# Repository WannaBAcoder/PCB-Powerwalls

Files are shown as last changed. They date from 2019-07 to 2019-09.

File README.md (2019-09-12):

# PCB-Powerwalls
This is the public file Repository for the [DIY PCB Powerwalls Community](https://www.facebook.com/groups/2573968699280898/). The projects are developed and maintained by **Vinnie Maro** and **Shaun Bond**.

We are developing a PCB alternative to common powerwall building techniques for 18650(and similar) batteries. This system has been developed with maintainability, expandability, and practicality in mind. 

For additional DIY Powerwall building resources, please check out some of the many other active facebook groups and forums:
* [DIY Powerwalls](https://www.facebook.com/groups/323586824654552/)
* [Jehu's DIY Powerwalls](https://www.facebook.com/groups/183620862292017/)
* [DIY Powerwall - easy](https://www.facebook.com/groups/244099703167519/)
* [Second Life Storage](https://secondlifestorage.com/index.php)

## Features in Development
To see features currently in development or exploration, check out our [issues](https://github.com/WannaBAcoder/PCB-Powerwalls/issues) page.

## 15s4p PCB

The 15s4p battery board is a stackable solution that reduces the amount of wiring required by placing all series and balance connections through standoffs that structurally connect the boards. Batteries mount to both sides of the PCB, in a variety of ways. Each cell is individually fused for added safety.

### 1. Plastic battery holders

You can choose to use plastic cell holders that are available in many through-hole and surface mount packages. For the through-hole packages, you must bend the pins at a 90 degree angle so that the holders sit as flat as possible.

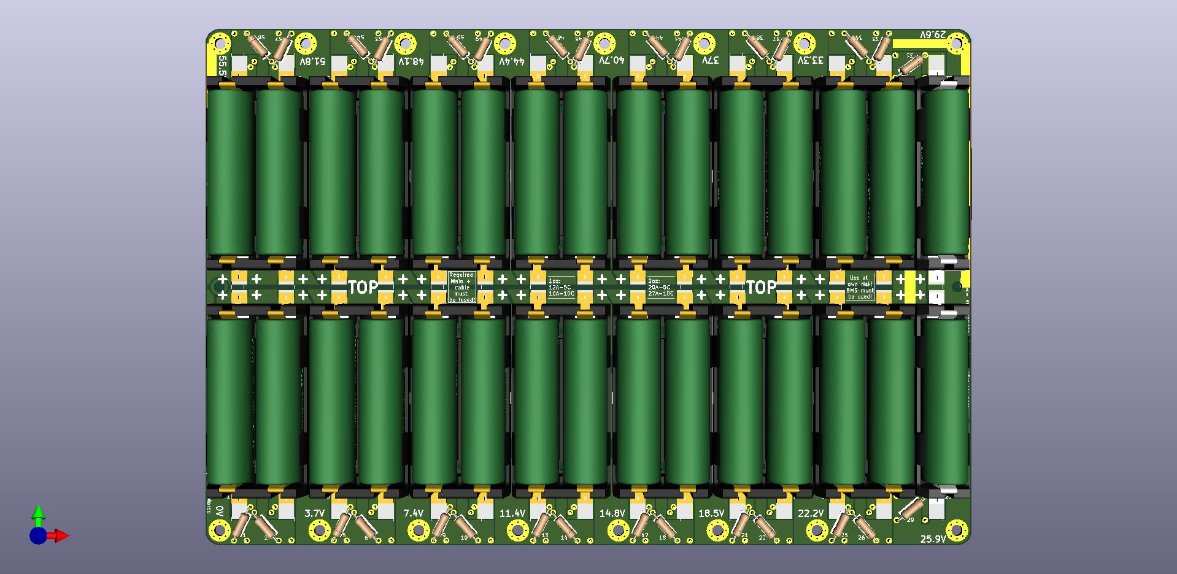
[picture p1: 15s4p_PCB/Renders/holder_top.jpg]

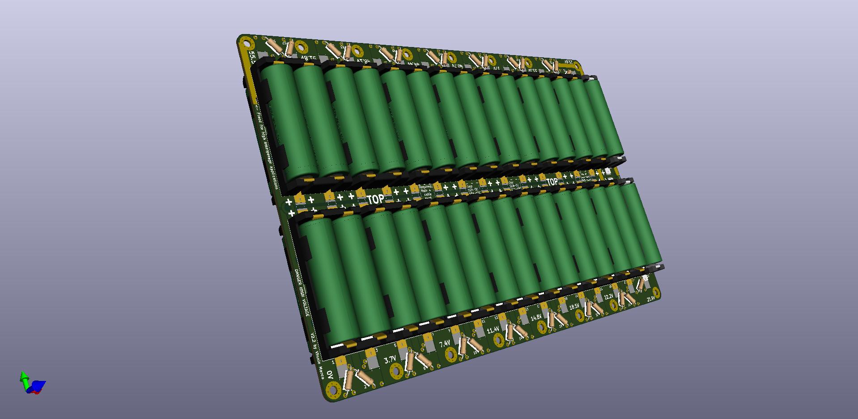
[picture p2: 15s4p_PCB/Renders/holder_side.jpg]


### 2. Spring clips

A cheaper alternative to plastic holders is spring clips. The clips work like traditional battery holders with springs, but these require the use of zip ties to hold the cells in place.

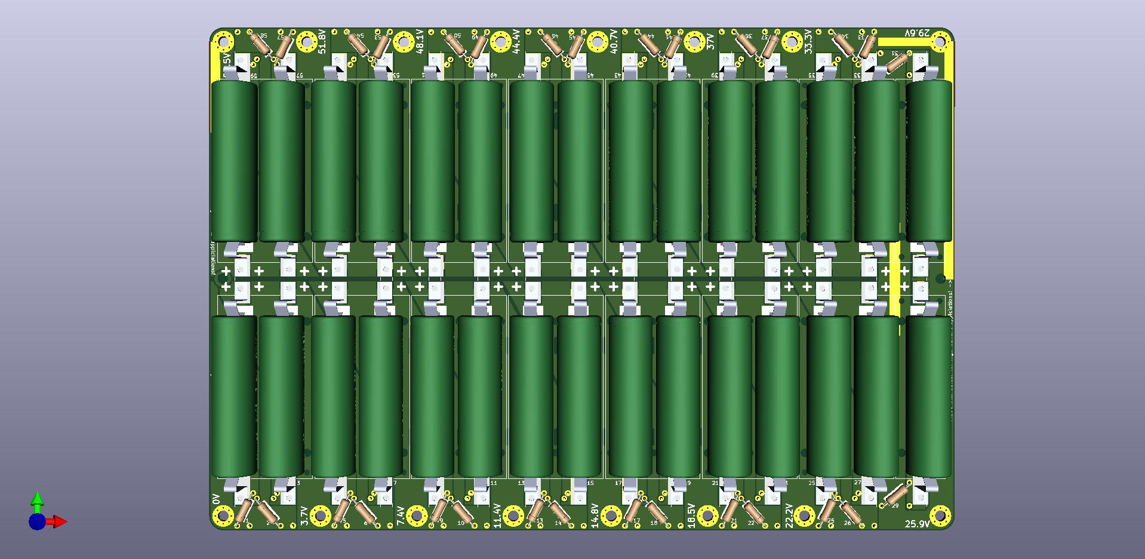
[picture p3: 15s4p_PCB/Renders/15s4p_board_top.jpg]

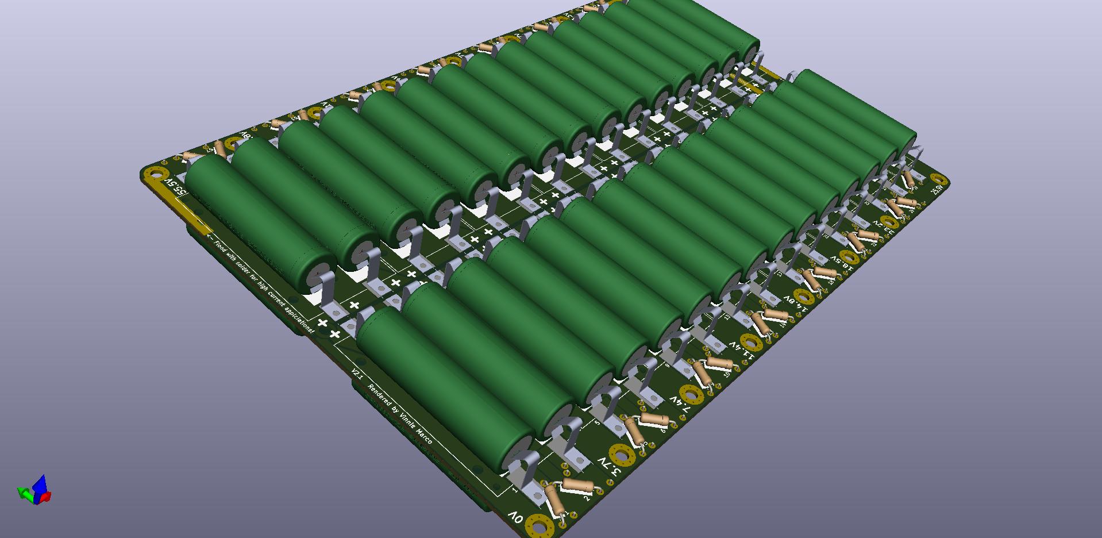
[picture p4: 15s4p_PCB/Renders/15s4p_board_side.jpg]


### 3. Fuse wire

The last option is to use fuse wire. You will still need to use zip ties to hold the cells in place, but you can solder the fuse wire directly to the PCB pads, and remove the need for populating fuses(you will need to short the fuse pads to do this). You can also use large fuse wire and still use fuses, if desired. Spotwelding fuse wire to the batteries and soldering the other end to the PCB pads is recommended.

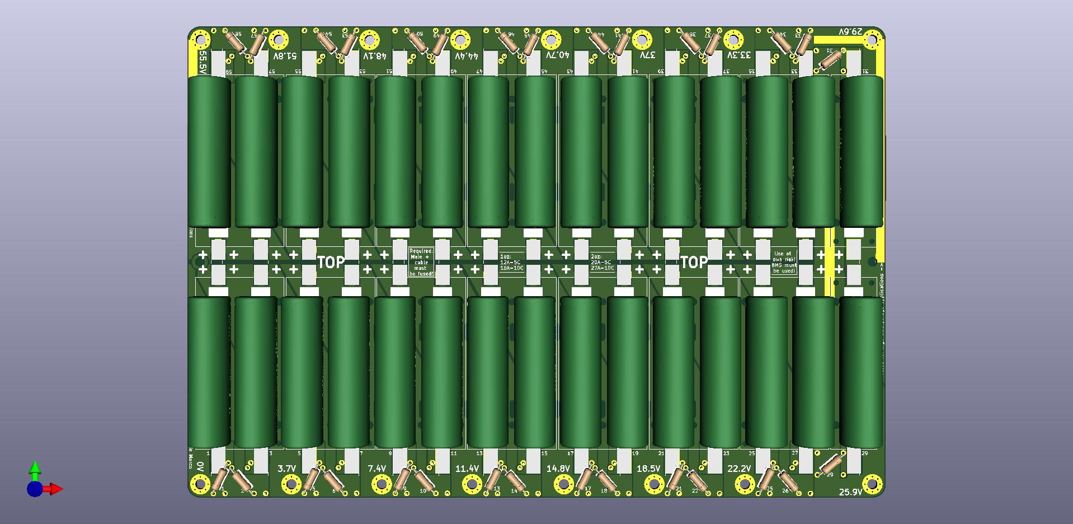
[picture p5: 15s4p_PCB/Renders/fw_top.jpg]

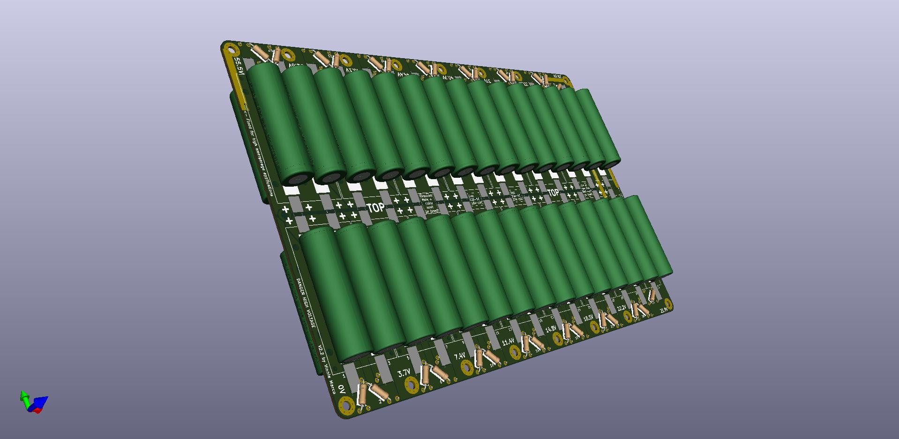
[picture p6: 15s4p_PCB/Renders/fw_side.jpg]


### 7s Adapter PCB

The 7s Adapter PCB was created to take our popular 15s4p design and convert it into a 7s8p PCB. We do this by leaving the out the 8s cells, which creates two 7s groups that get connected in parallel. It is recommended to use at least one of these adapter PCBs for every 5 boards, or 20A of main fuse(which is 10A load on each of these boards). This board also joins the battery stacks with standoffs. It's important to equally space these boards within a pack for best current distribution. For example, a 12 battery board stack could use 3 adapter boards, spaced every 4 boards.

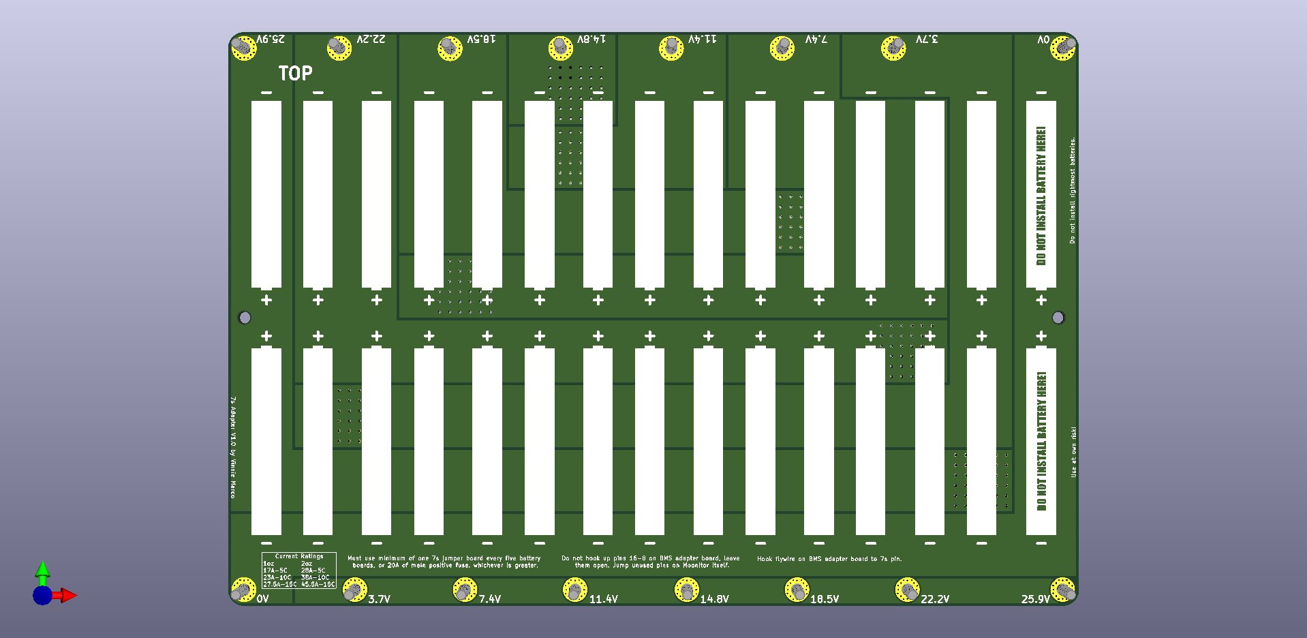
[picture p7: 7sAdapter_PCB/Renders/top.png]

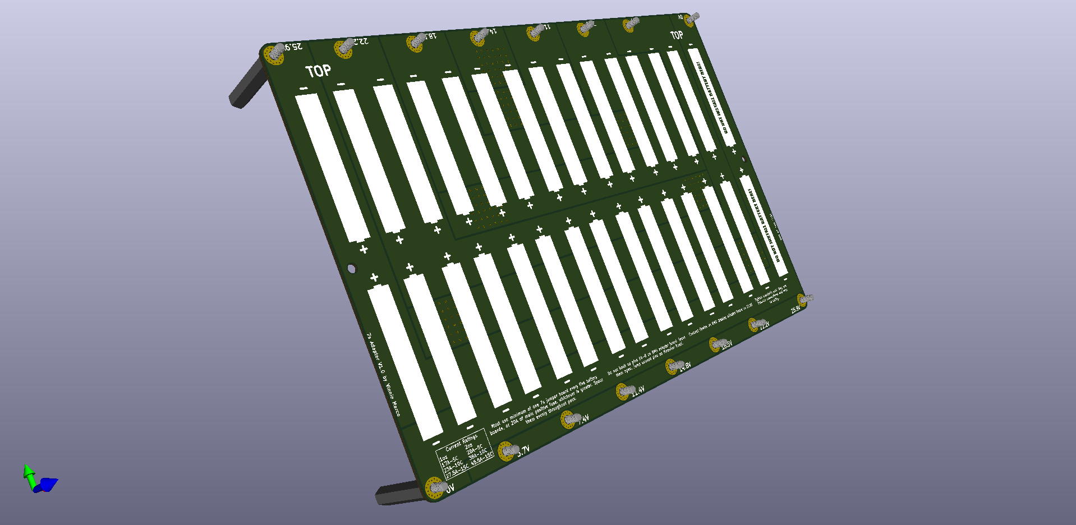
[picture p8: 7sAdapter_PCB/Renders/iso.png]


### BMS/Display Adapter PCB

The BMS/display adapter board helps the user connect a [Moonitor](https://www.sarperonal.com/product/6s-16s-solar-plc-li-ion-battery-protection-system/), or a variety of BMS systems to the battery PCB stacks, and is capable of supporting ~5A balance current. This board also includes spaces to add series-level voltage displays, but they can be disabled if not desired.  You can also use this board with the 7s adapter board configurations.

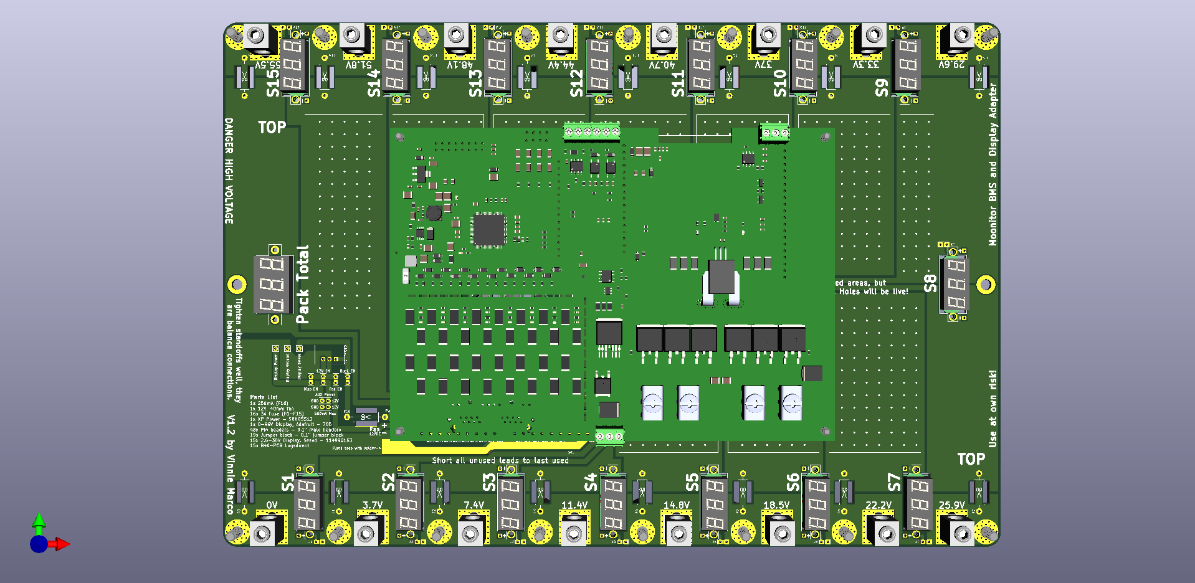
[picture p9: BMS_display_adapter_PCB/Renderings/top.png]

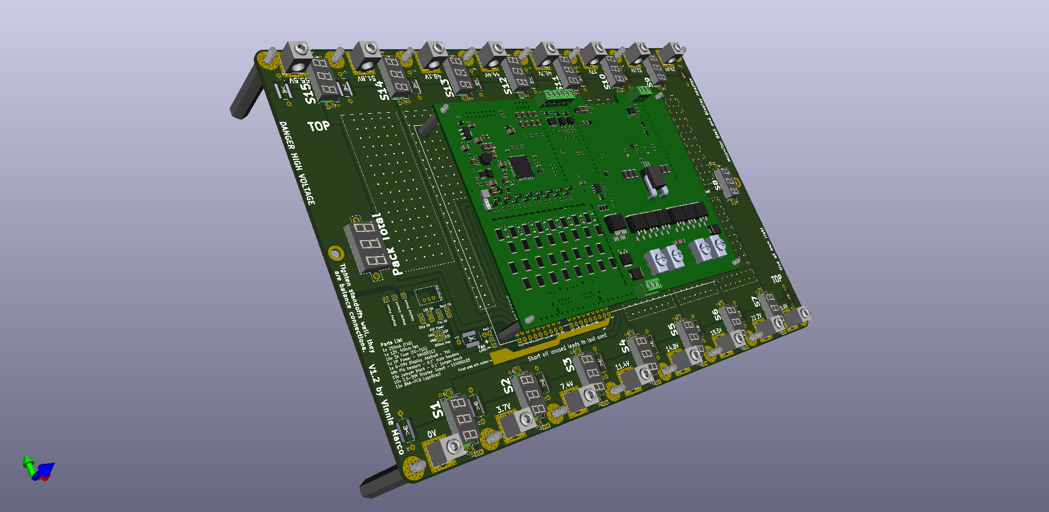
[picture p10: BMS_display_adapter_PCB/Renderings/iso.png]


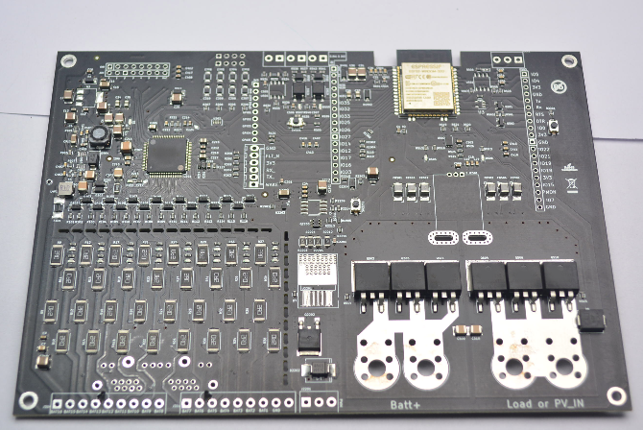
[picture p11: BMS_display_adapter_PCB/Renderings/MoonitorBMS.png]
moonitor view


## Building Your Own

### Ordering the PCBs

You can order your own boards from any number of PCB manufacturers. Many of our supporters use [JLCPCB.com](https://jlcpcb.com/quote).

**Recommended manufacturing options:**
* PCB thickness - 1.6mm
* PCB color-Your choice (black is not available for 2oz copper orders)
* Surface finish - HASL(with lead)
* Copper weight - 1oz or 2oz **(Higher current applications use 2oz)**
* All other options can be left as default

### Ordering Parts
#### Common Parts
* M4 Standoffs(40mm for SMD plastic holders, 45mm for through-hole plastic holders, may be able to make 40mm work with zip tie methods if zipties are alternated. Not confirmed at this time)
    -  [Nickel plated steel](https://www.aliexpress.com/item/33009686876.html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)
    - [Brass](https://www.aliexpress.com/item/32909068891.html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)
    
* 60x Glass Axial Fuses
**Choosing the right fuse is based on tradeoff between usebility and saftey. Even a 0.5A fuse can't protect against all 18650(and similar) failure modes. Shaun Bond's testing suggests 0.5A fuses are the ideal size for safety, but impractical for all massive builds with low load. You should still consider your pack-loading characteristics when choosing them.**
  - [0.5A](https://www.ebay.com/itm/200Pcs-Glass-Fuse-Tube-Axial-With-Lead-Wire-Fast-Blows-Fuse-3x10mm-250V-0-5A-US-/283481427034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)
  - [1A](https://www.ebay.com/i/372678478703?itemid=372678478703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)
  - [1.5A](https://www.ebay.com/itm/200Pcs-Glass-Fuse-Tube-Axial-With-Lead-Wire-Fast-Blows-Fuse-3x10mm-250V-1-5A-P/401758396012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)
  - [2A](https://www.ebay.com/i/283303754606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)
  - [3A](https://www.ebay.com/itm/200Pcs-Glass-Fuse-Tube-Axial-With-Lead-Wire-Fast-Blows-Fuse-3x10mm-250V-3A-US/283485834501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)
  - [aliexpress](https://www.aliexpress.com/item/32910625856.html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)
    
#### 15s4p PCB
**Be sure to choose the right holders for your desired build. For plastic holder builds, the quantities assume using only 1-cell and 2cell, or 3-cell and 4-cell holders per board. 
* Plastic Holders
  - 4x 1-cell holder([Keystone 1042](https://www.keyelco.com/product.cfm/product_id/918))
    - [mouser](https://www.mouser.com/ProductDetail/Keystone-Electronics/1042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)
    - [aliexpress](https://www.aliexpress.com/item/32843455571.html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,searchweb201602_4,searchweb201603_52)

  - 28x 2-cell holder([Keystone 1048](https://www.keyelco.com/product.cfm/product_id/920)) 
    - [mouser](https://www.mouser.com/ProductDetail/Keystone-Electronics/1048?qs=%2F7TOpeL5Mz5jXkg8vI8Dyw%3D%3D)
    - [aliexpress](https://www.aliexpress.com/item/32810550974.html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,searchweb201602_4,searchweb201603_52)

  - 4x 3-cell holder(BK-18650-PC6)(through-hole)
    - [digikey](https://www.digikey.com/product-detail/en/mpd-memory-protection-devices/BK-18650-PC6/BK-18650-PC6-ND/2330514)
    - [aliexpress](https://www.aliexpress.com/item/32855470302.html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,searchweb201602_7,searchweb201603_53)

  - 24x 4-cell holder(BK-18650-PC8)(through-hole)
    - [digikey](https://www.digikey.com/product-detail/en/mpd-memory-protection-devices/BK-18650-PC8/BK-18650-PC8-ND/2330515)
    - [aliexpress](https://www.aliexpress.com/item/32813957846.html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,searchweb201602_7,searchweb201603_53)
       
* 120x Spring clips([Keystone 5331](https://www.keyelco.com/product.cfm/product_id/823))
    - [mouser](https://www.mouser.com/ProductDetail/Keystone-Electronics/5331?qs=poiiR8sYdC9oC9Ij8wI9kA%3D%3D)
    - [newark](https://www.newark.com/keystone/5331/battery-contact-a-aa-2-3a-cell/dp/25T0473)
 
#### BMS/Display Adapter PCB
* 1x Total voltage pack voltage display(Adafruit 705)
    - [mouser](https://www.digikey.com/products/en/industrial-automation-and-controls/panel-meters/805?k=adafruit%20705)
    - [Adafruit](https://www.adafruit.com/product/705
    
* 15x Series-group voltage display(Seeed 114990163)
    - [mouser](https://www.mouser.com/ProductDetail/Seeed-Studio/114990163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)
    - [Seeed](https://www.seeedstudio.com/0-28-Inch-LED-digital-DC-voltmeter-Green-p-2287.html)
    - [Digikey](https://www.digikey.com/products/en/industrial-automation-and-controls/panel-meters/805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) has other colors too.
    
* 1x 12VDC 40x40mm PC Fan(2-wire)
    - Tons of these on [Amazon](https://www.amazon.com/WINSINN-Brushless-40x40x10mm-Extruder-Makerbot/dp/B0757LXKST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)

* 1x 75VDC to 12V buck converter module.
    - [mouser](https://www.mouser.com/ProductDetail/XP-Power/SRH05S12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)
    - [Digikey](https://www.digikey.com/products/en?keywords=srh05s12)
    
* 1x 0.25A glass fuse
    - [Digikey](https://www.digikey.com/product-detail/en/littelfuse-inc/0251.250NRT1L/F5997CT-ND/4146349)
    - [mouser](https://www.mouser.com/ProductDetail/Littelfuse/0251250NRT1L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)
    - [Ebay](https://www.ebay.com/itm/200Pc-Glass-Tube-Fuse-Metal-Axial-Double-Hat-Fast-Blow-Fuse-3-6x10mm-250V-0-25A/264389811818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)

* 16x B4A Lugs
    - [hex](https://lugsdirect.com/B4A-PCB-HEX.html)
    
* 0.1" male pin headers
    - [aliexpress](https://www.aliexpress.com/item/32899255706.html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,searchweb201602_7,searchweb201603_53)
    
* 0.1" jumper blocks
    - [aliexpress](https://www.aliexpress.com/item/32972892184.html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,searchweb201602_7,searchweb201603_53)
 
* Moonitor BMS

You can purchase this BMS from the Moonitor team on their [website](https://www.sarperonal.com/product/6s-16s-solar-plc-li-ion-battery-protection-system/). You can also contact [them](https://www.sarperonal.com/contact-us/) directly for more information.

### Building Instructions and Documentation
Check out the [wiki](https://github.com/WannaBAcoder/PCB-Powerwalls/wiki) for assembly instructions, and additional information.

## Versioning

Each powerwall PCB has its own revision in the form of VX.X. In addition to this, we version the entire system package in a release in the form of RX.0. See the latest release for the most recent hardware package. Whenever any of the hardware in a package changes, the PCB version and package release will be updated. PCB versions are printed on all PCBs for easy identification.

## Contributing

Although the kicad source files are available, the safety considerations that go into this project make it potentially unsafe to modify; do so at your own risk! You can always contribute to the development of this project by suggesting improvements or new features desired by reporting them as [issues](https://github.com/WannaBAcoder/PCB-Powerwalls/issues).

## License

This project is licensed under the CERN Open Hardware License - see the [LICENSE.txt](LICENSE.txt) file for details.

## Acknowledgments

A special thank you to the people and communities that inspired or helped develop the early versions of this hardware and helped others realize the growing potential for these designs:
* Shaun Bond
* Izz Eselam
* Paulo E Cabigao
* Dale Bliss
* Jehu Garcia 
* Andrew Hunt
* Daniel Wiermans

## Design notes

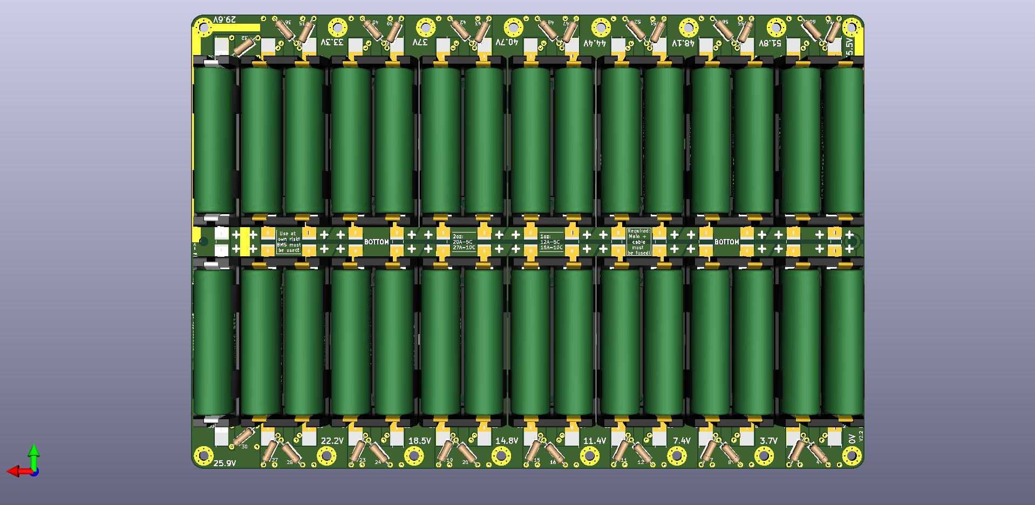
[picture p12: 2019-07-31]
15s4p_PCB/Renders/holder_bottom.jpg

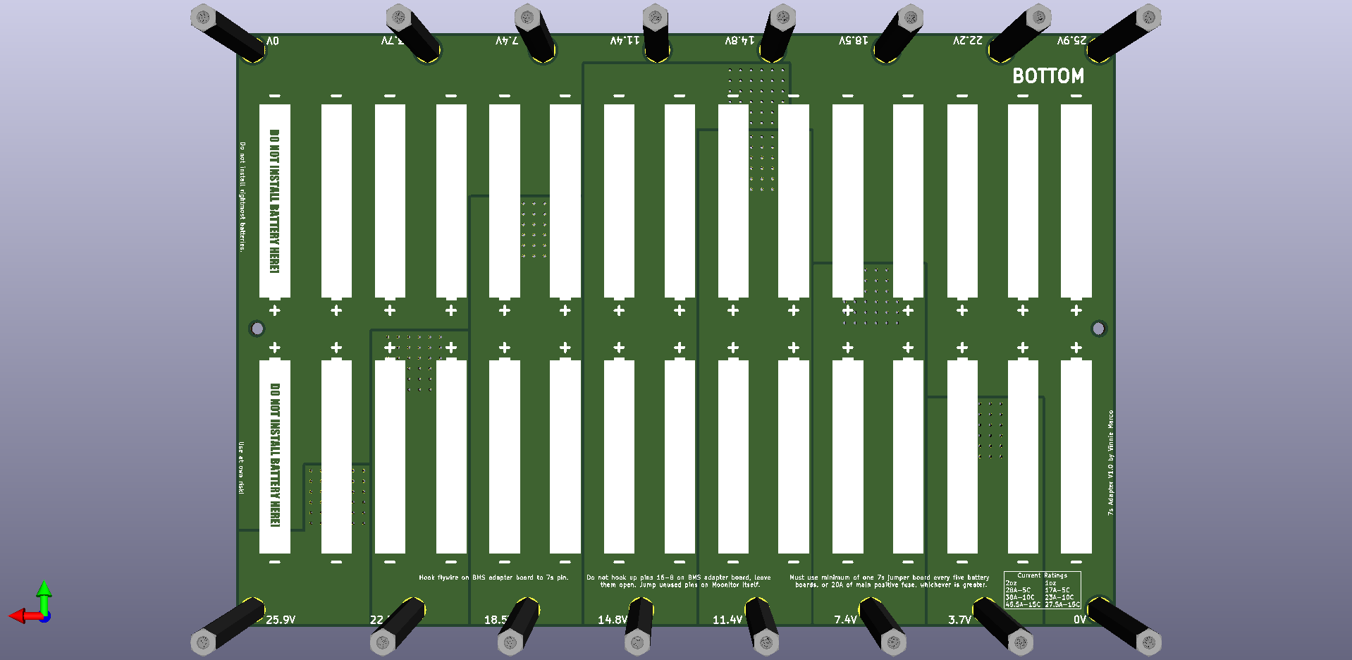
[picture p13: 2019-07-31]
7sAdapter_PCB/Renders/bottom.png

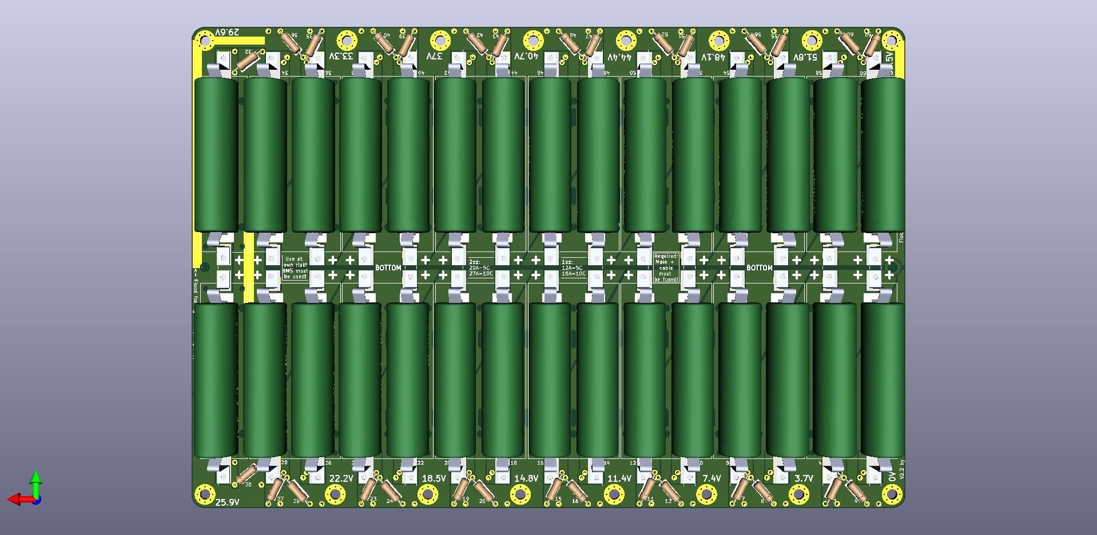
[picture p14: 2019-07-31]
15s4p_PCB/Renders/bottom.jpg

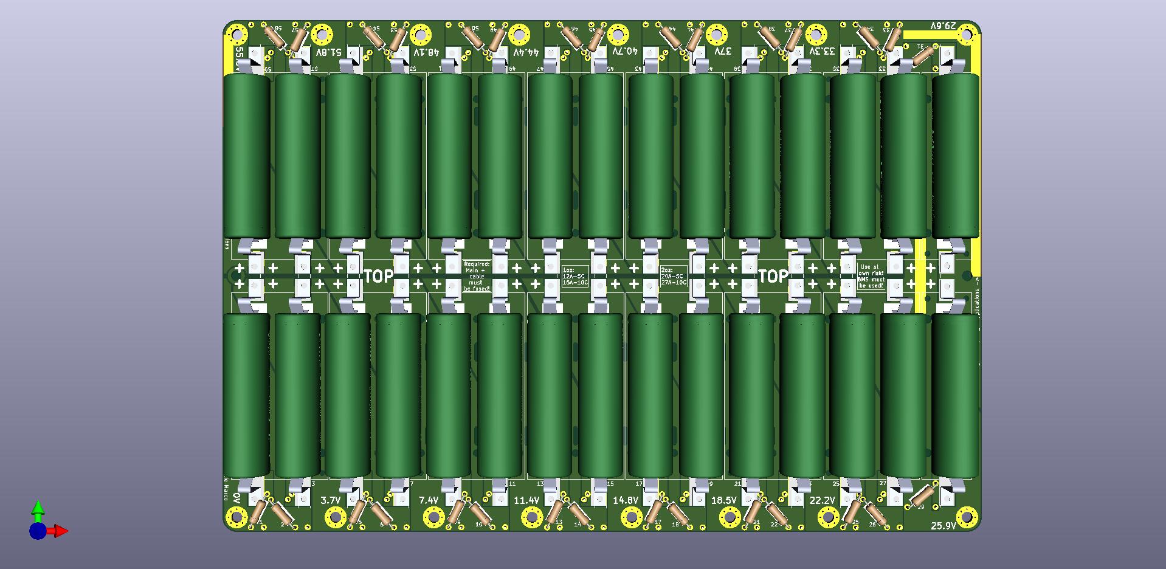
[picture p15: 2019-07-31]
15s4p_PCB/Renders/top.jpg

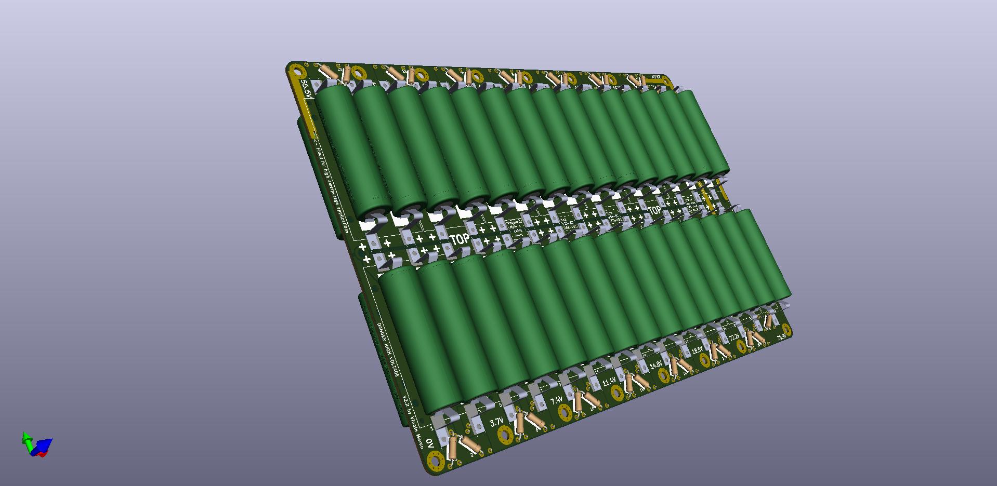
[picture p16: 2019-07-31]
15s4p_PCB/Renders/side.jpg

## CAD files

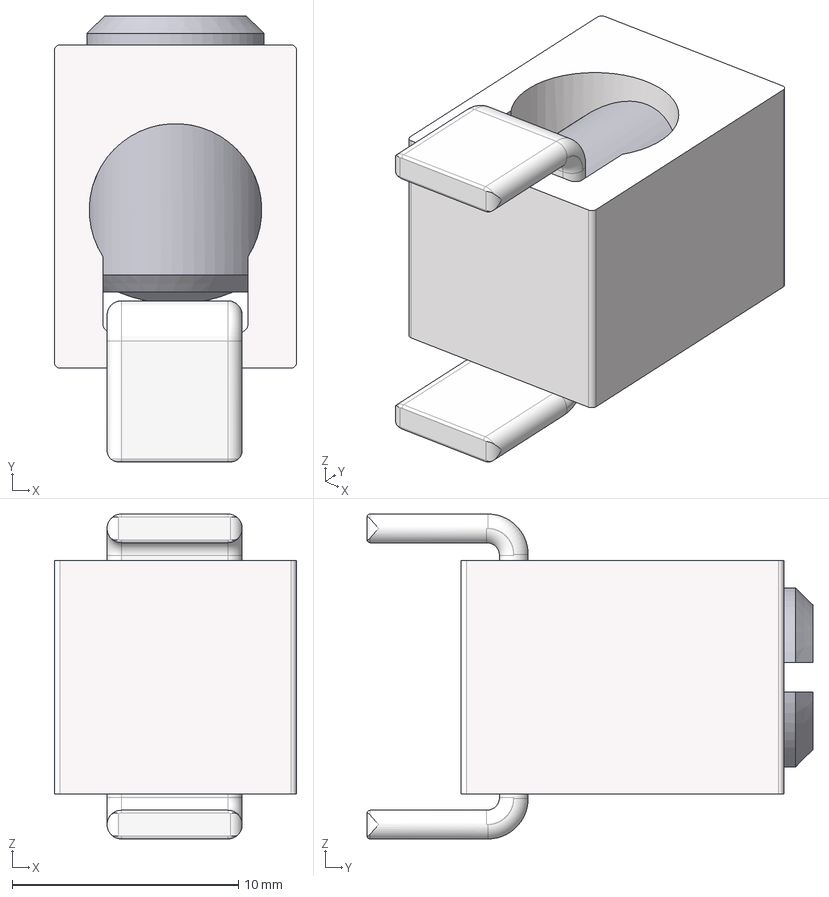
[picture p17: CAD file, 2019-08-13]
BMS_display_adapter_PCB/3D Models/_STP FILES_B2A-PCB-Assembly.stp
10.7 x 19.7 x 14.4 mm
B2A

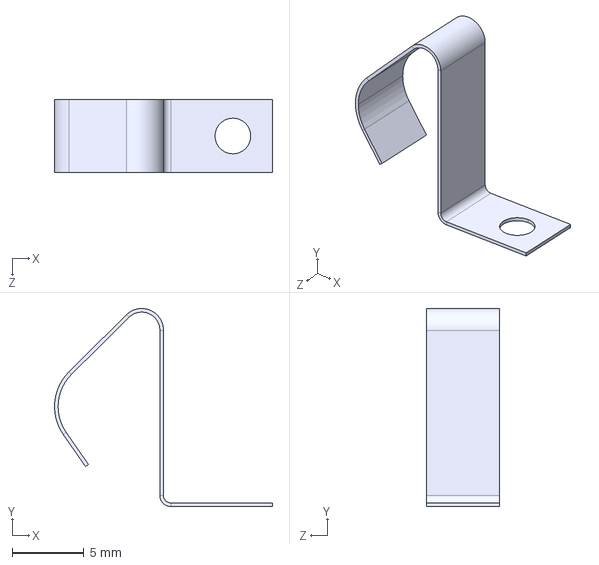
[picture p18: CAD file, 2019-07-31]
15s4p_PCB/3D Models/keystone-PN5331.STEP
15.2 x 13.8 x 5.08 mm

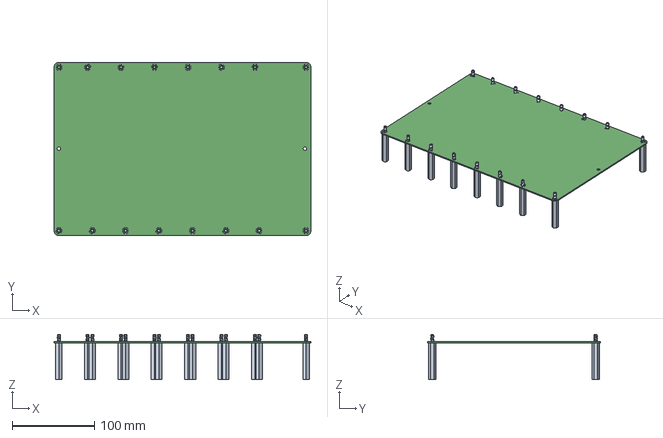
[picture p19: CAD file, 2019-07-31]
7sAdapter_PCB/7sAdapter.step
313.0 x 211.0 x 55.0 mm

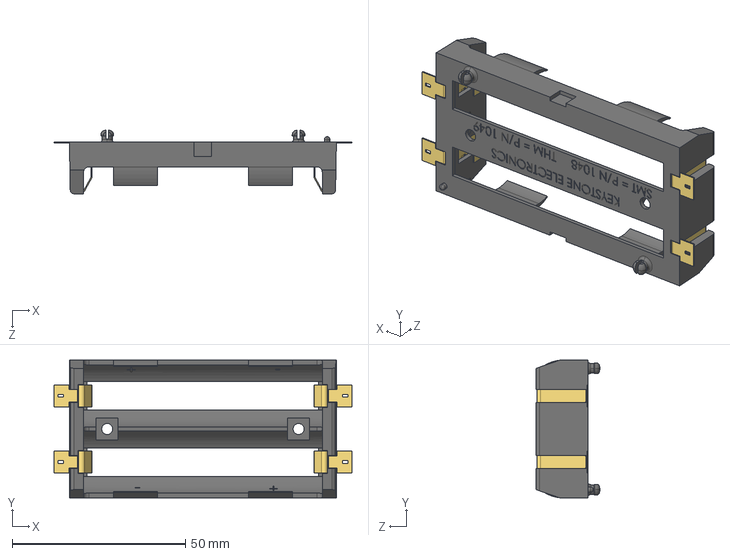
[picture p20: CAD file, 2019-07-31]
15s4p_PCB/3D Models/keystone-PN1047.STEP
86.0 x 39.8 x 18.3 mm

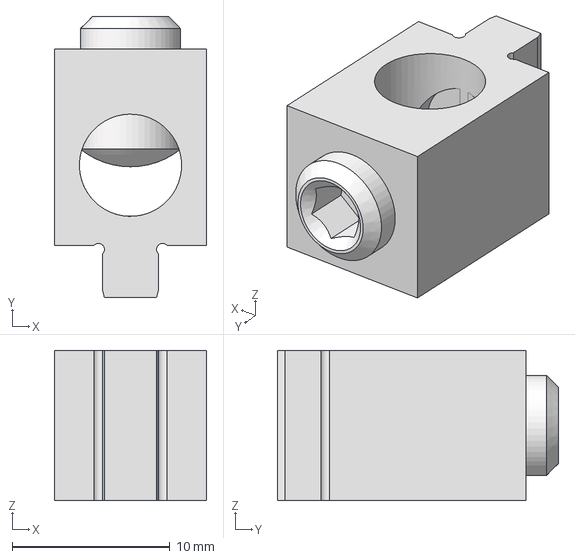
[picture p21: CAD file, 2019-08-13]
BMS_display_adapter_PCB/3D Models/_STP FILES_B4A-PCB-HEX.stp
9.65 x 17.8 x 9.53 mm
B4A-PCB

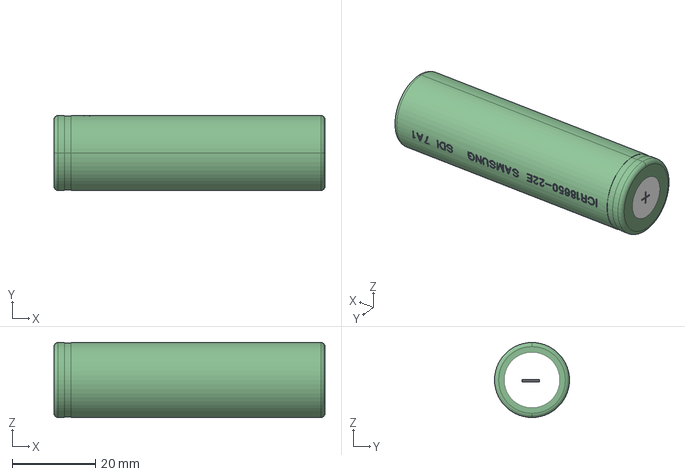
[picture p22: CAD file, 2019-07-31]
15s4p_PCB/3D Models/Battery Samsung ICR 18650 -22E.stp
65.0 x 18.0 x 18.0 mm

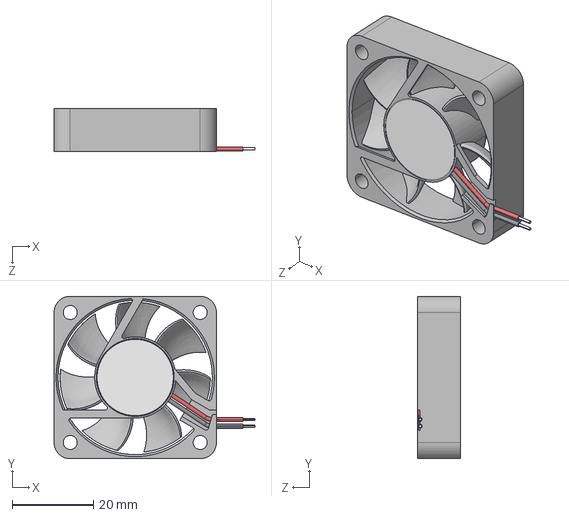
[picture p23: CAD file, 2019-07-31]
BMS_display_adapter_PCB/3D Models/40x40x10 DC Fan.STEP
49.5 x 40.0 x 10.5 mm

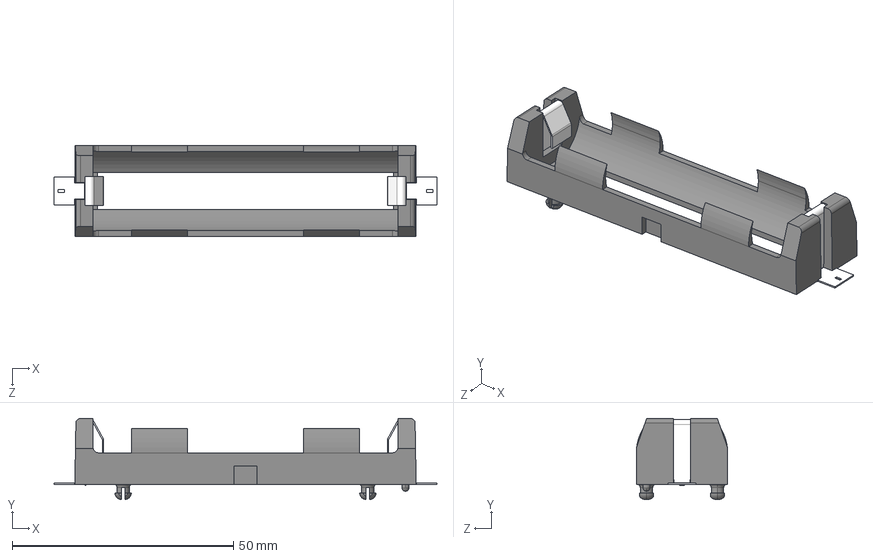
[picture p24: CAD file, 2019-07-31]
15s4p_PCB/3D Models/1042--3DModel-STEP-56544.STEP
86.5 x 18.3 x 20.7 mm

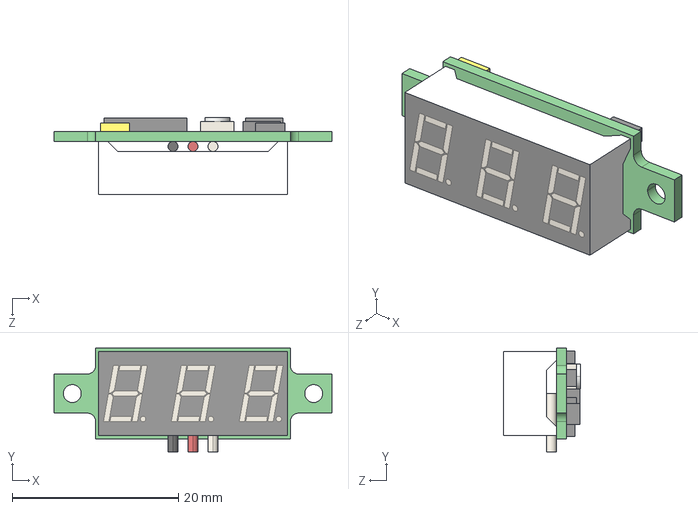
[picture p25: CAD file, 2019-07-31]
BMS_display_adapter_PCB/3D Models/LED DC 0-100V Digital Voltmeter Panel Meter.STEP
33.4 x 12.5 x 9.30 mm

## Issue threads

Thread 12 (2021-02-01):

JLCPCB.COM - Reply when sending order for BMS

xxxxminingxxxx, 2021-02-01:
Hi Sir,

Well got your order with many thanks~
Sorry to bother you, but there is an issue that we want to confirm with you before proceeding.

As shown below, the plated slots in your file are too long , there is a risk of blasting holes after tinned. can you accept that potencial risk without any quality complaint about this issue ?If yes ,we can continue this order ,as as you can check the capability listed on our website ,the maximum plated holes/slots we can accept is 6.3mm .we suggest you can change HASL to ENIG to reduce the risk .

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

Your early reply will be highly appreciated!

WannaBAcoder, 2021-02-01:
Hello,

I think they have been able to produce this before. See attached:
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

Based on that, I think it's safe to accept the risk.

Thanks,
Vinnie Marco

xxxxminingxxxx, 2021-02-06:
Hello,

I let you know that I have ordered the 15S4P boards and the BMS board.
Thanks for sharing, fantastic job!
I normally have them next week, let you know how it goes.
I will also link the Moonitor16S to this.

Mvg, Mark

Op ma 1 feb. 2021 om 16:50 schreef WannaBAcoder <notifications@github.com>:

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

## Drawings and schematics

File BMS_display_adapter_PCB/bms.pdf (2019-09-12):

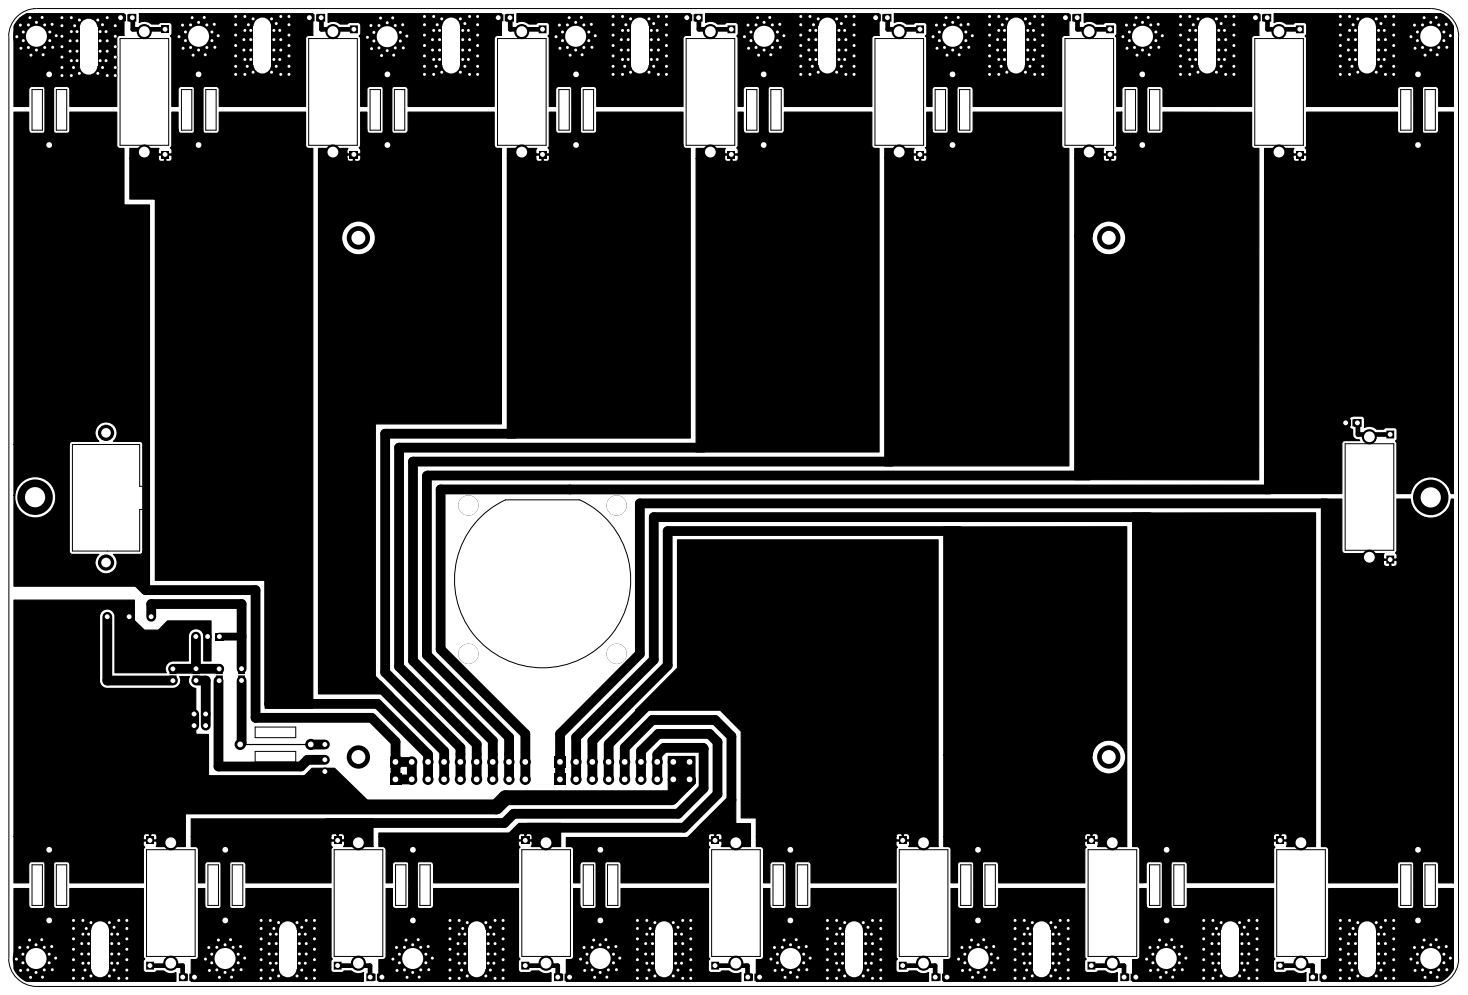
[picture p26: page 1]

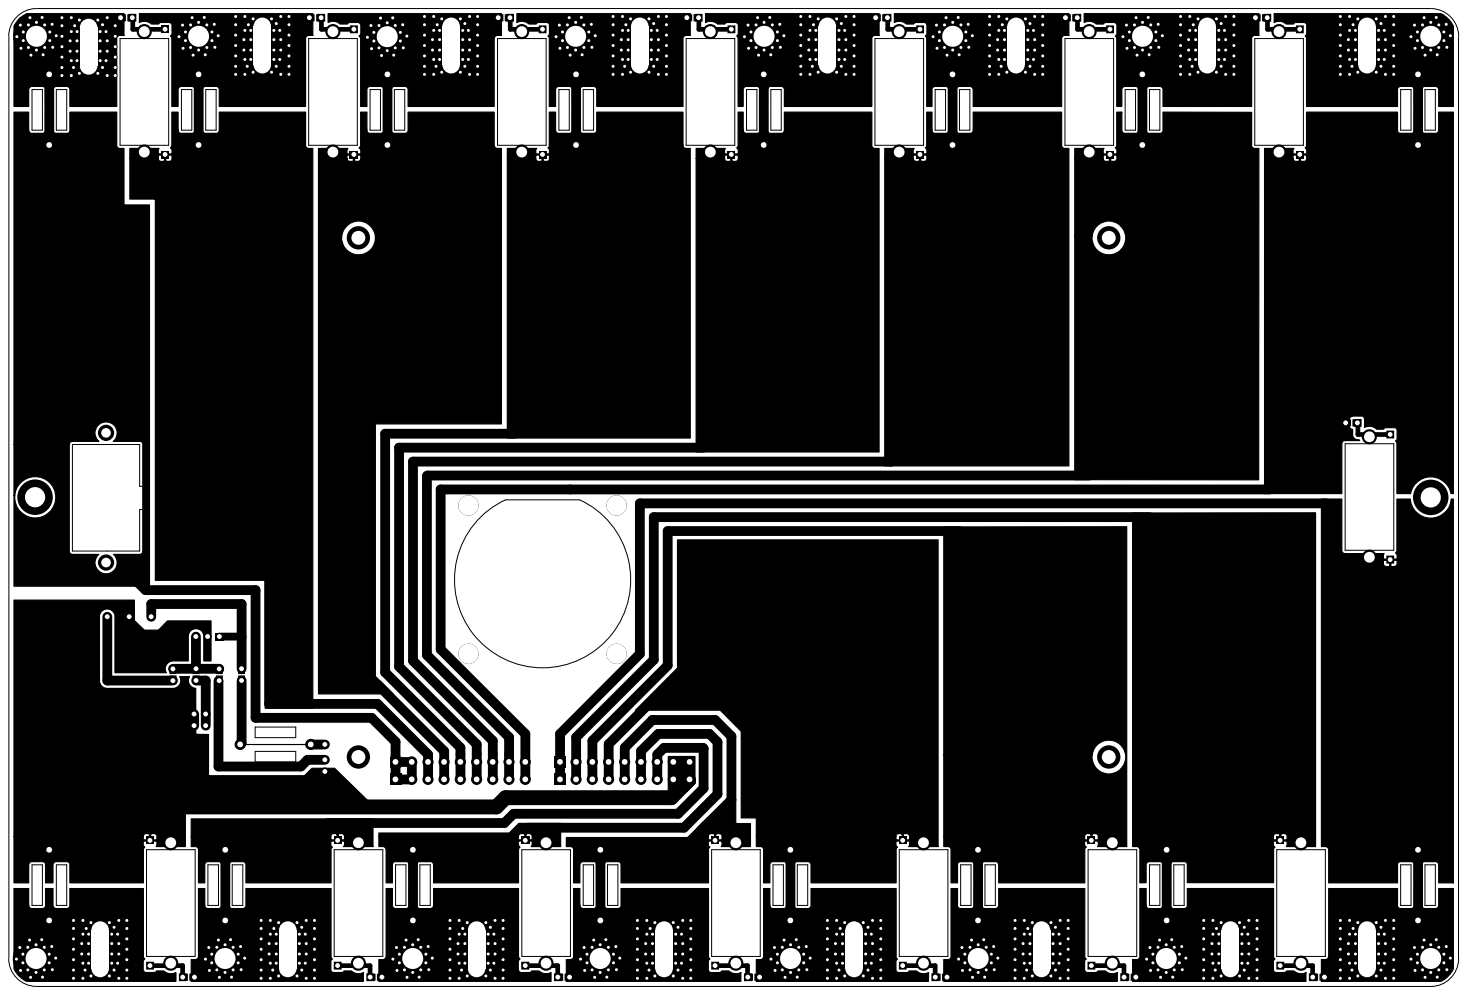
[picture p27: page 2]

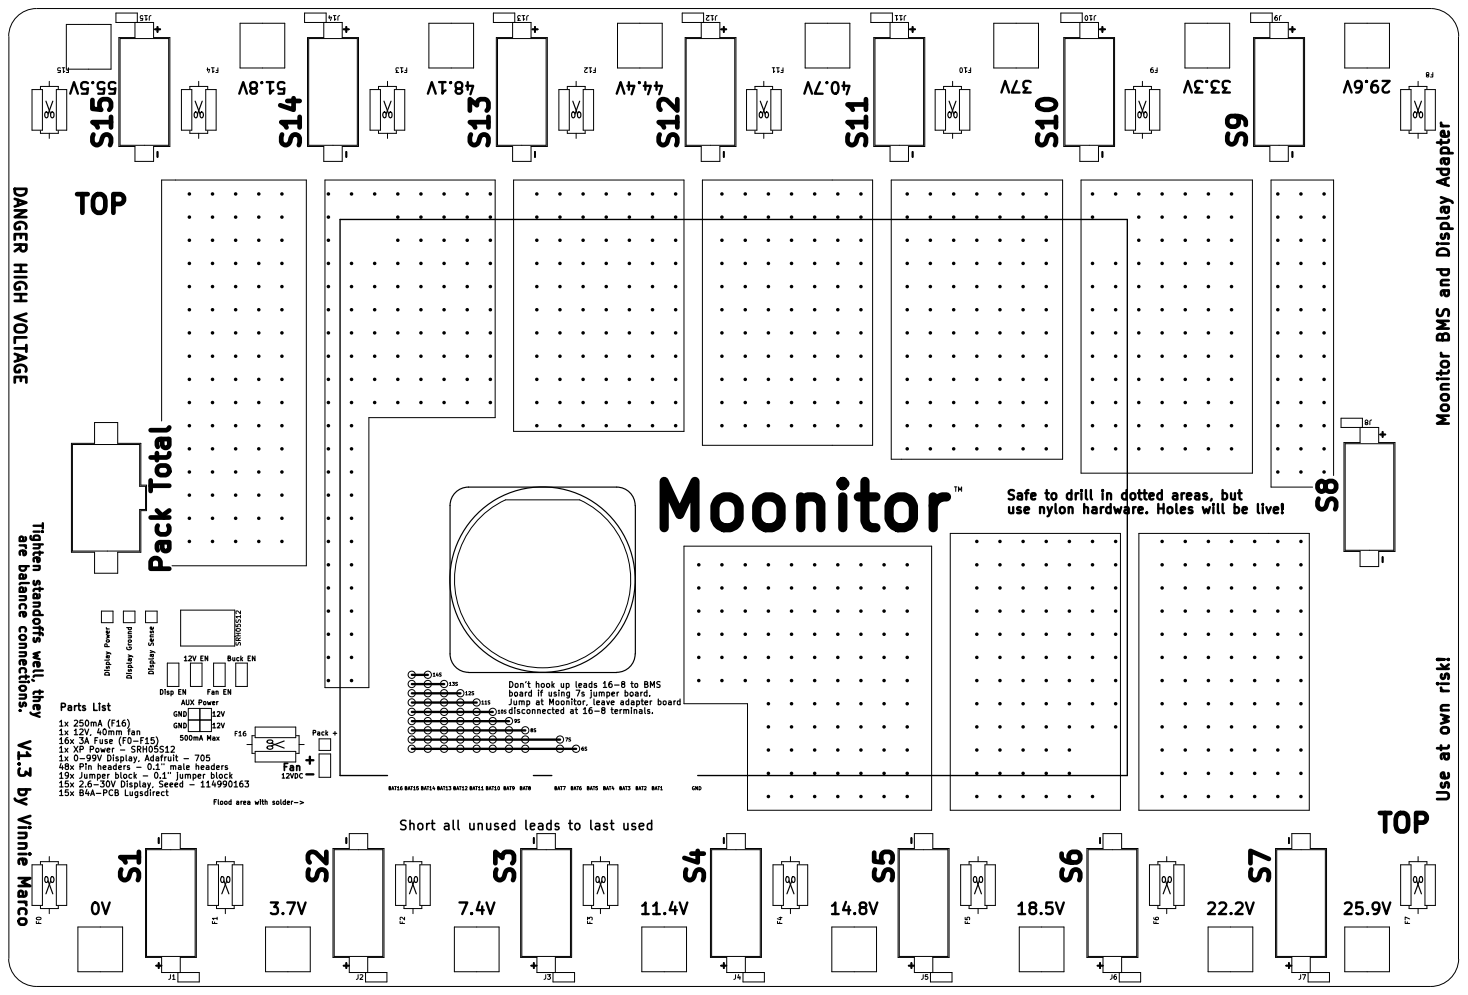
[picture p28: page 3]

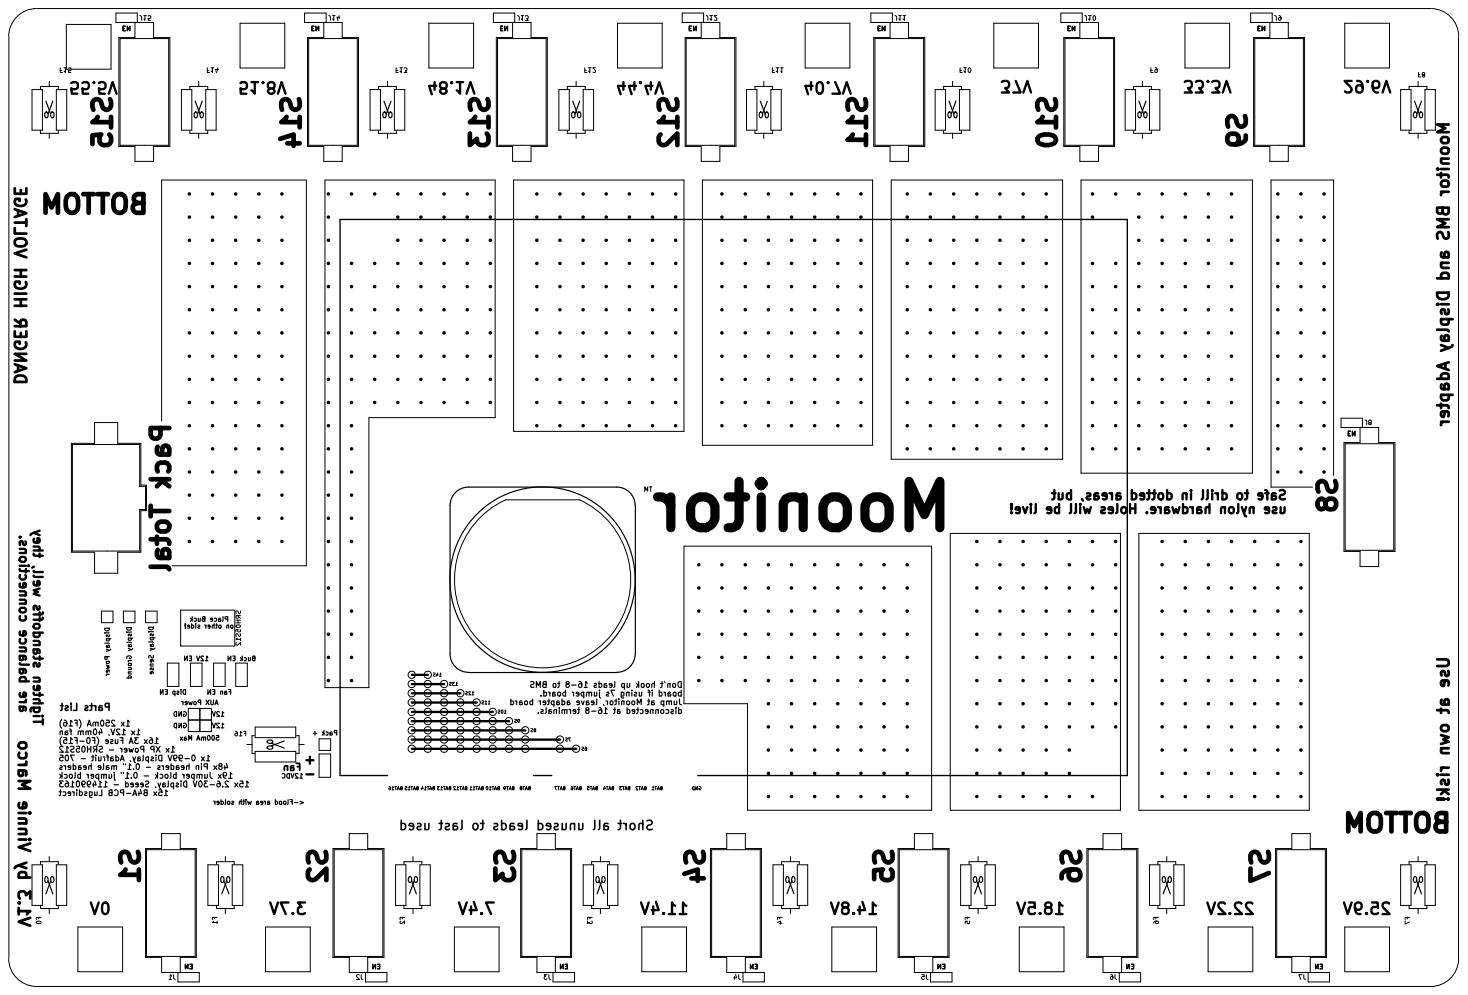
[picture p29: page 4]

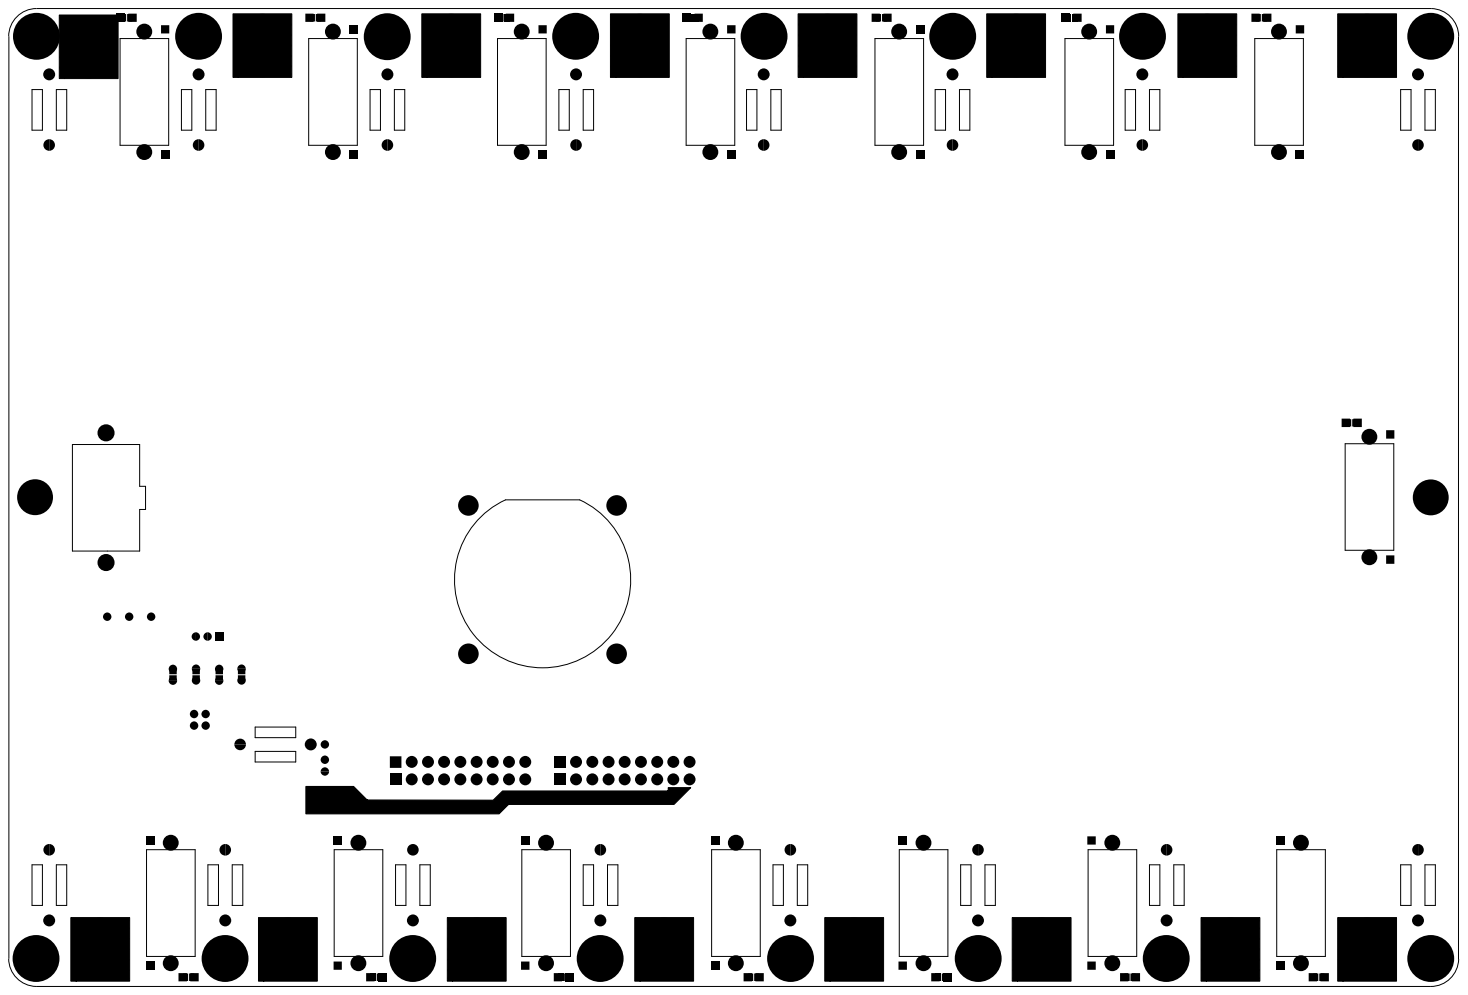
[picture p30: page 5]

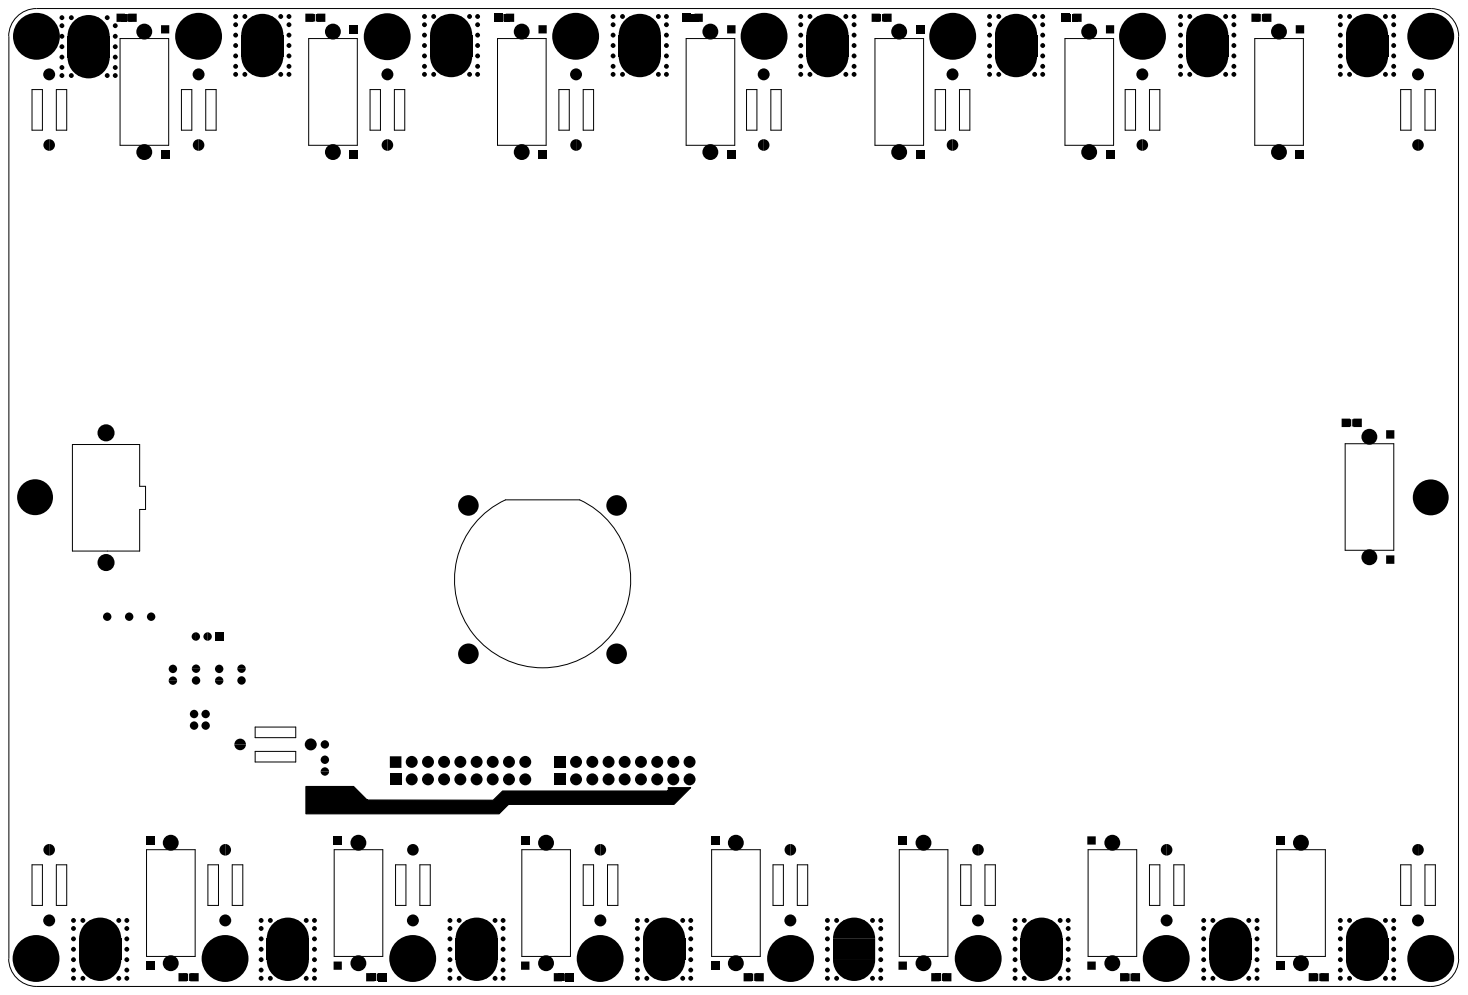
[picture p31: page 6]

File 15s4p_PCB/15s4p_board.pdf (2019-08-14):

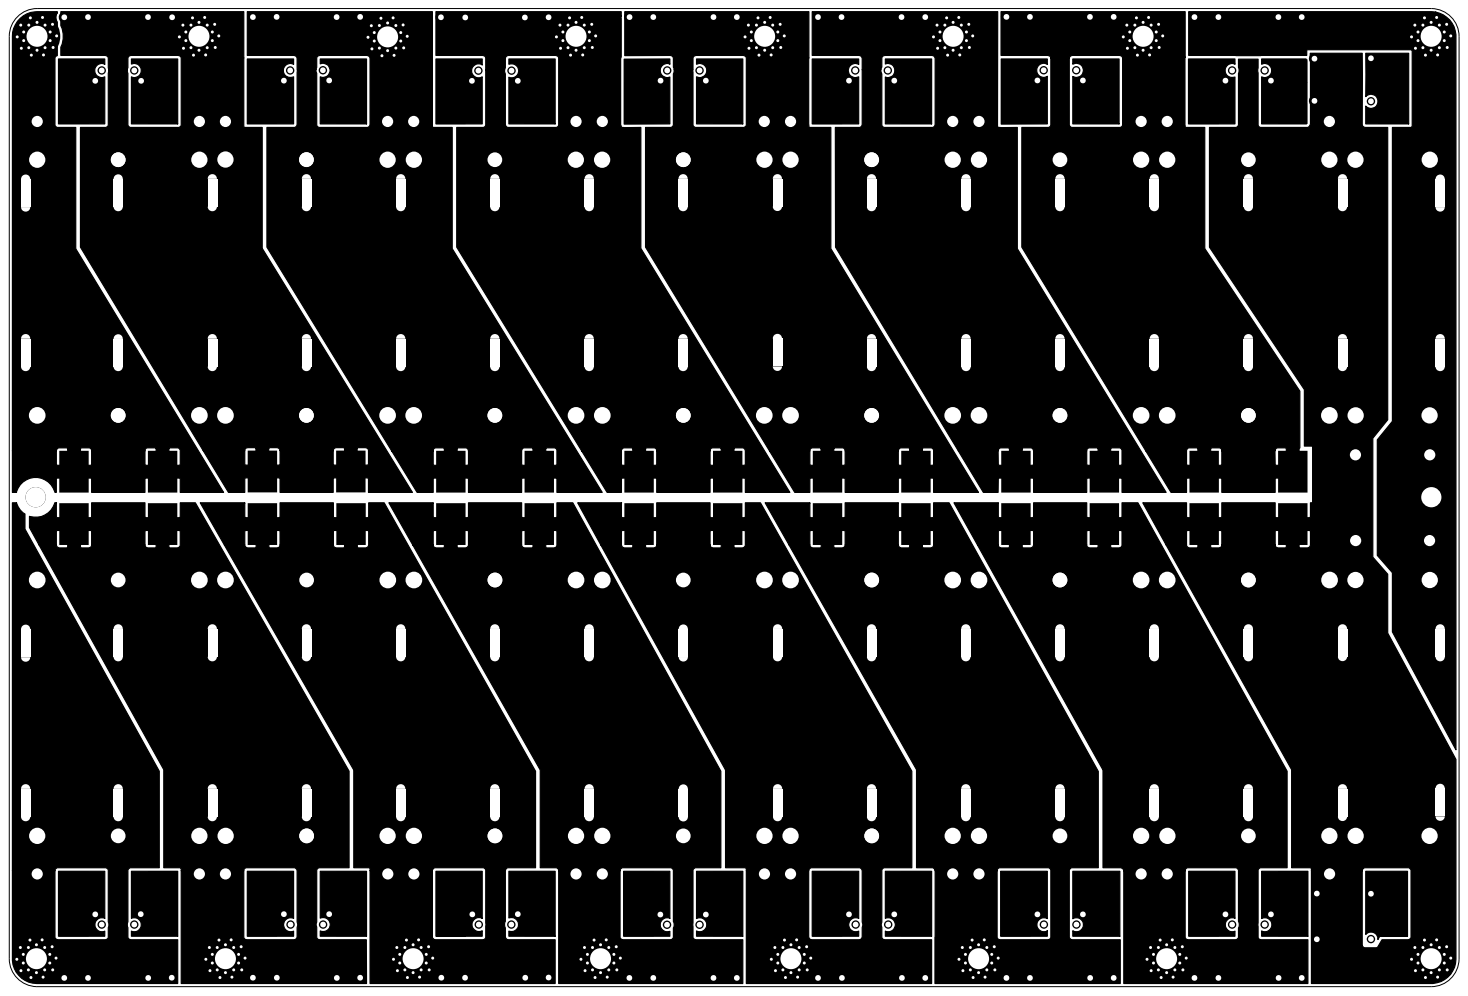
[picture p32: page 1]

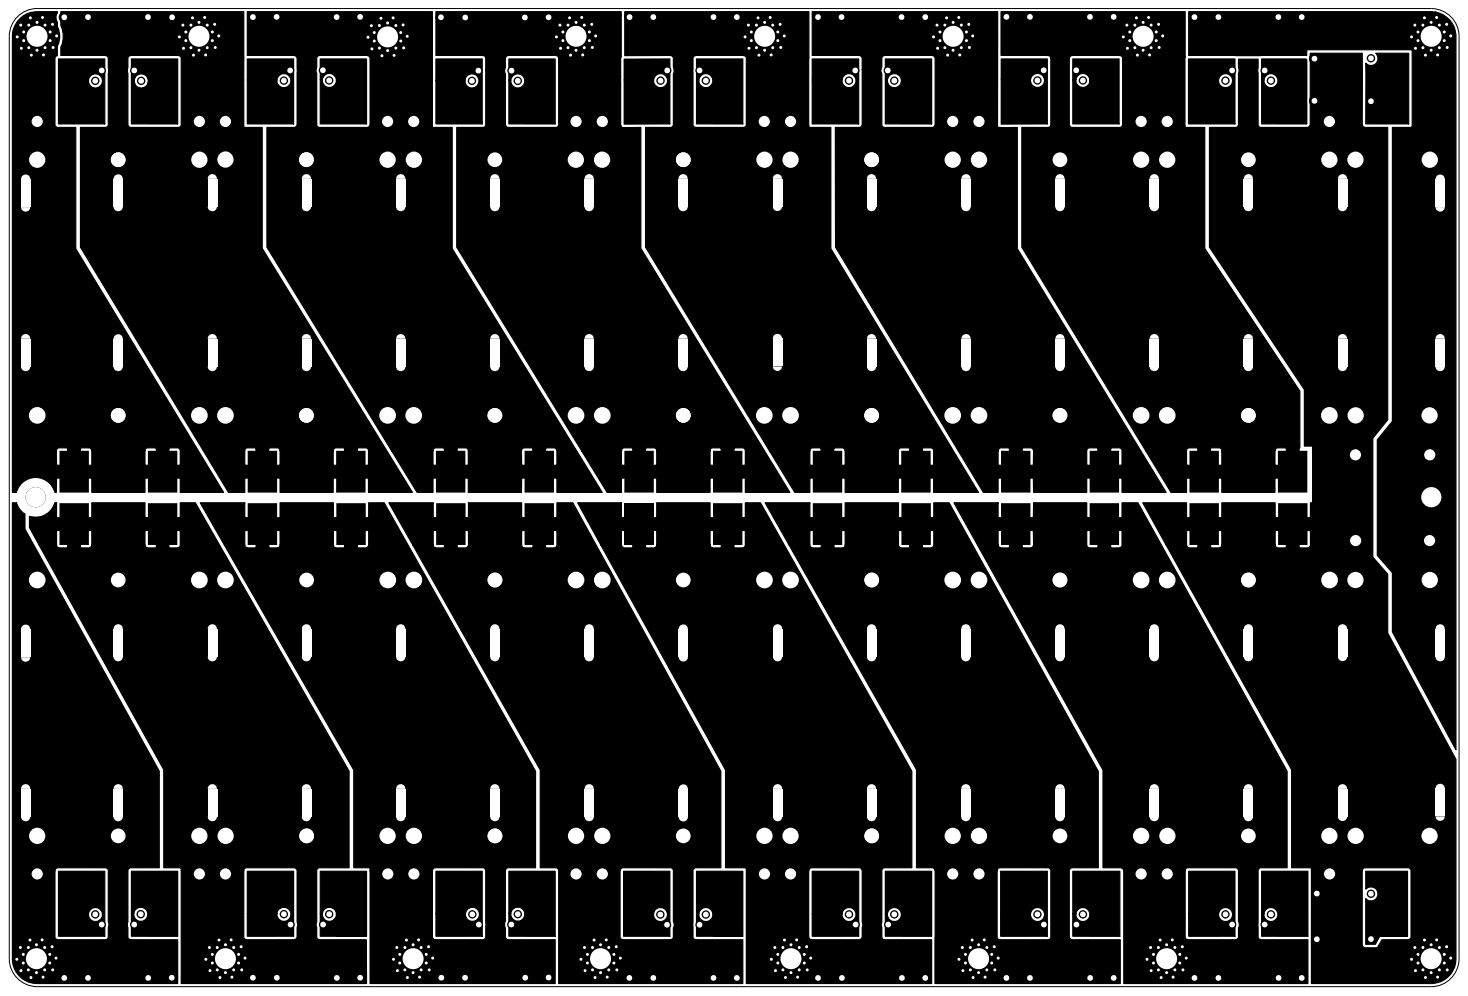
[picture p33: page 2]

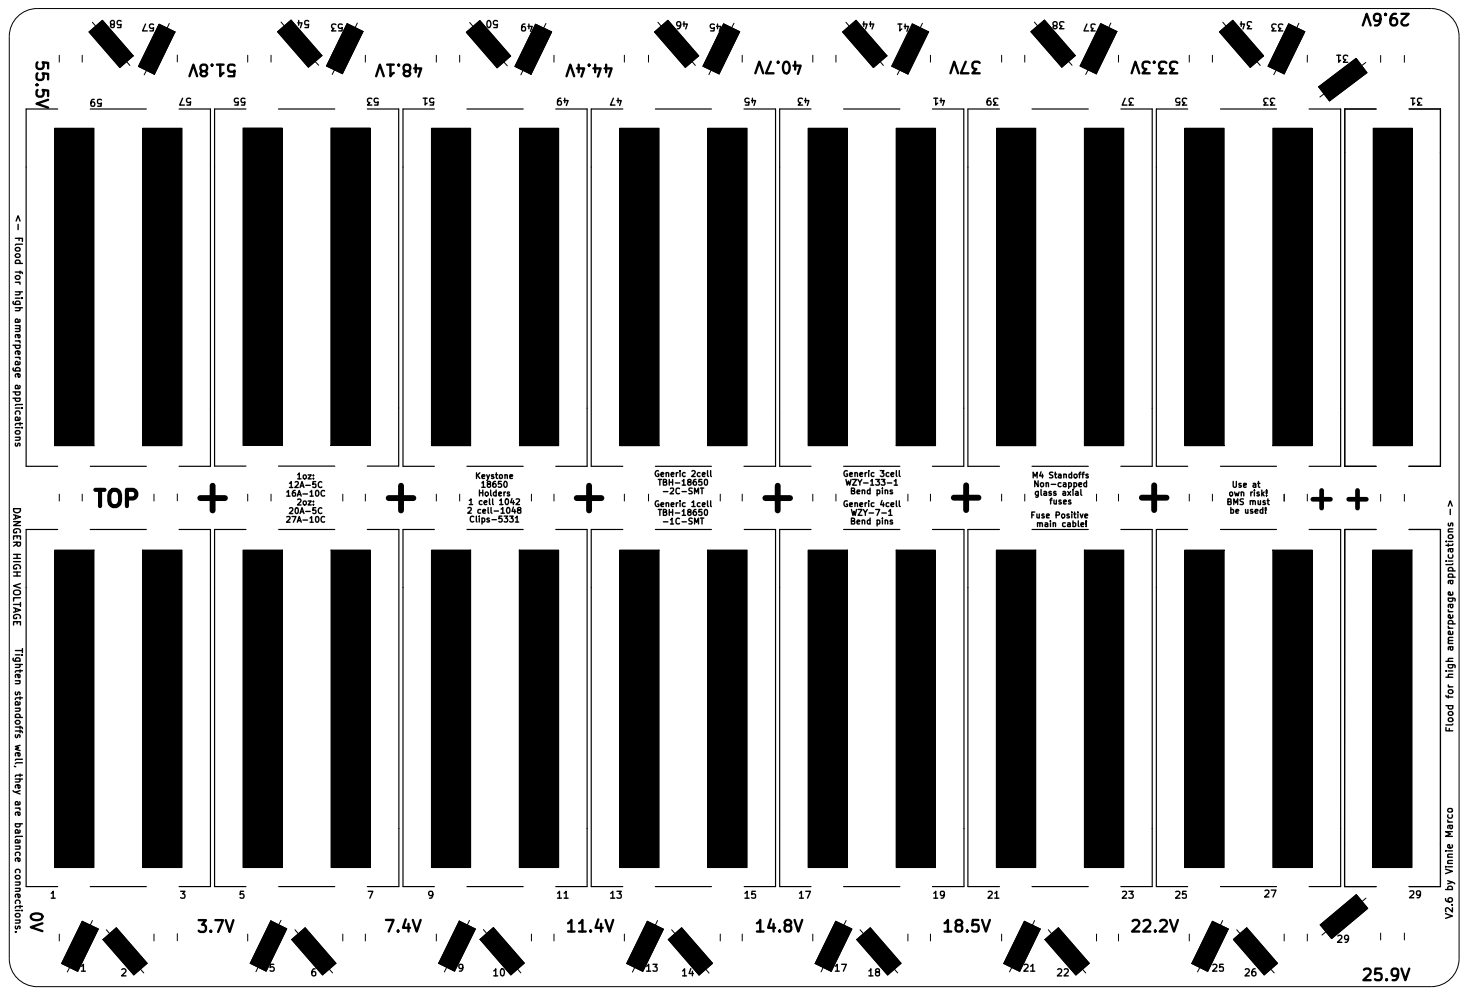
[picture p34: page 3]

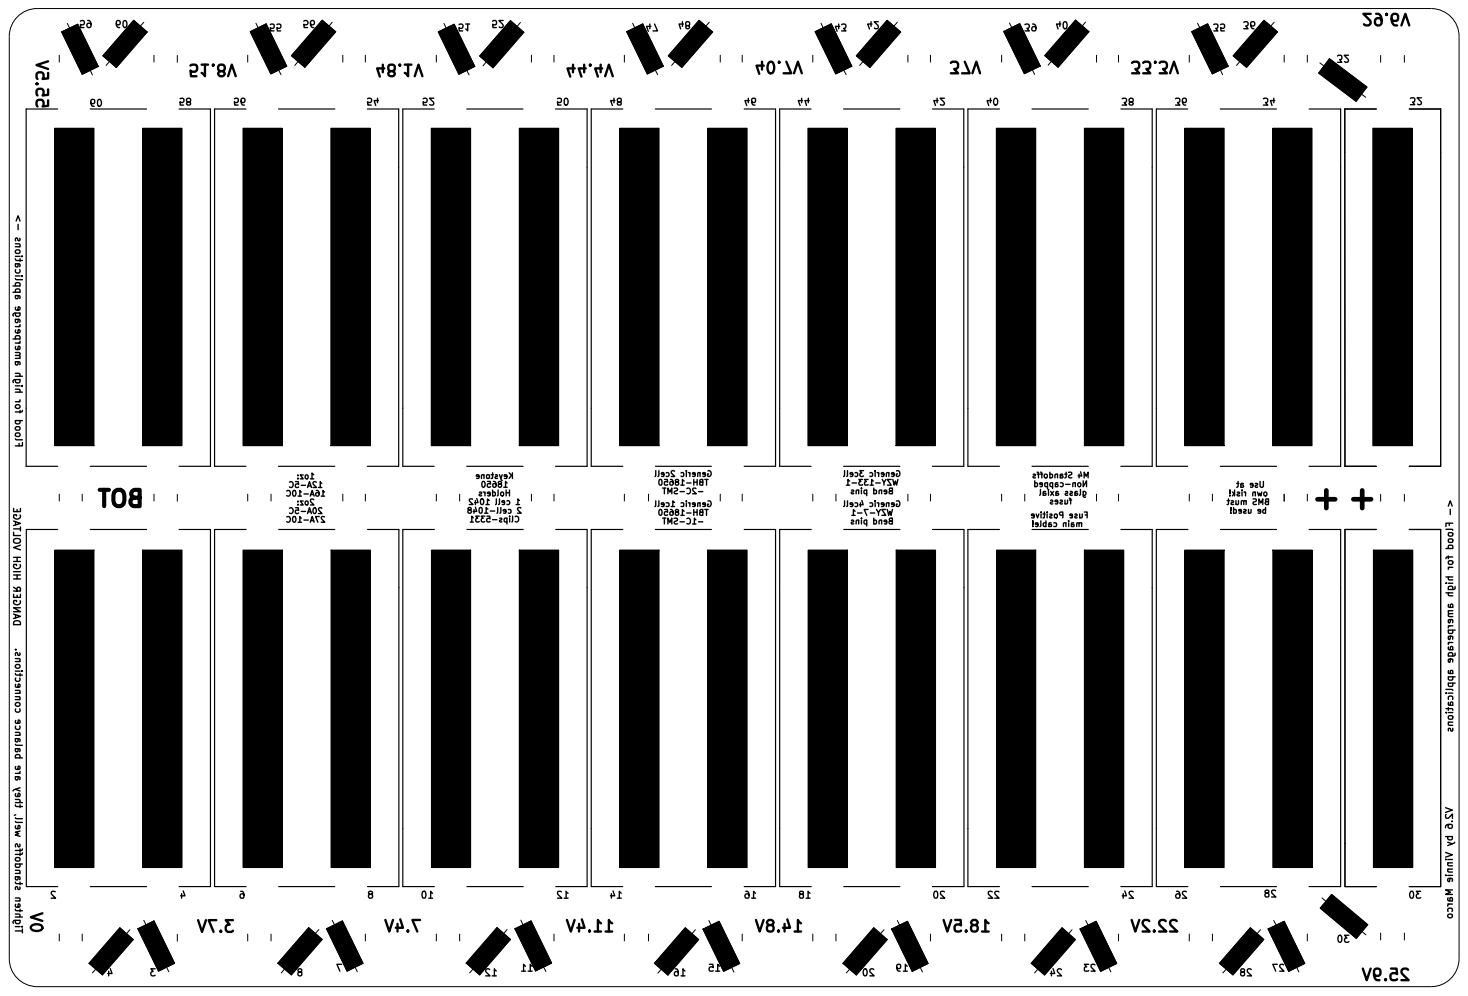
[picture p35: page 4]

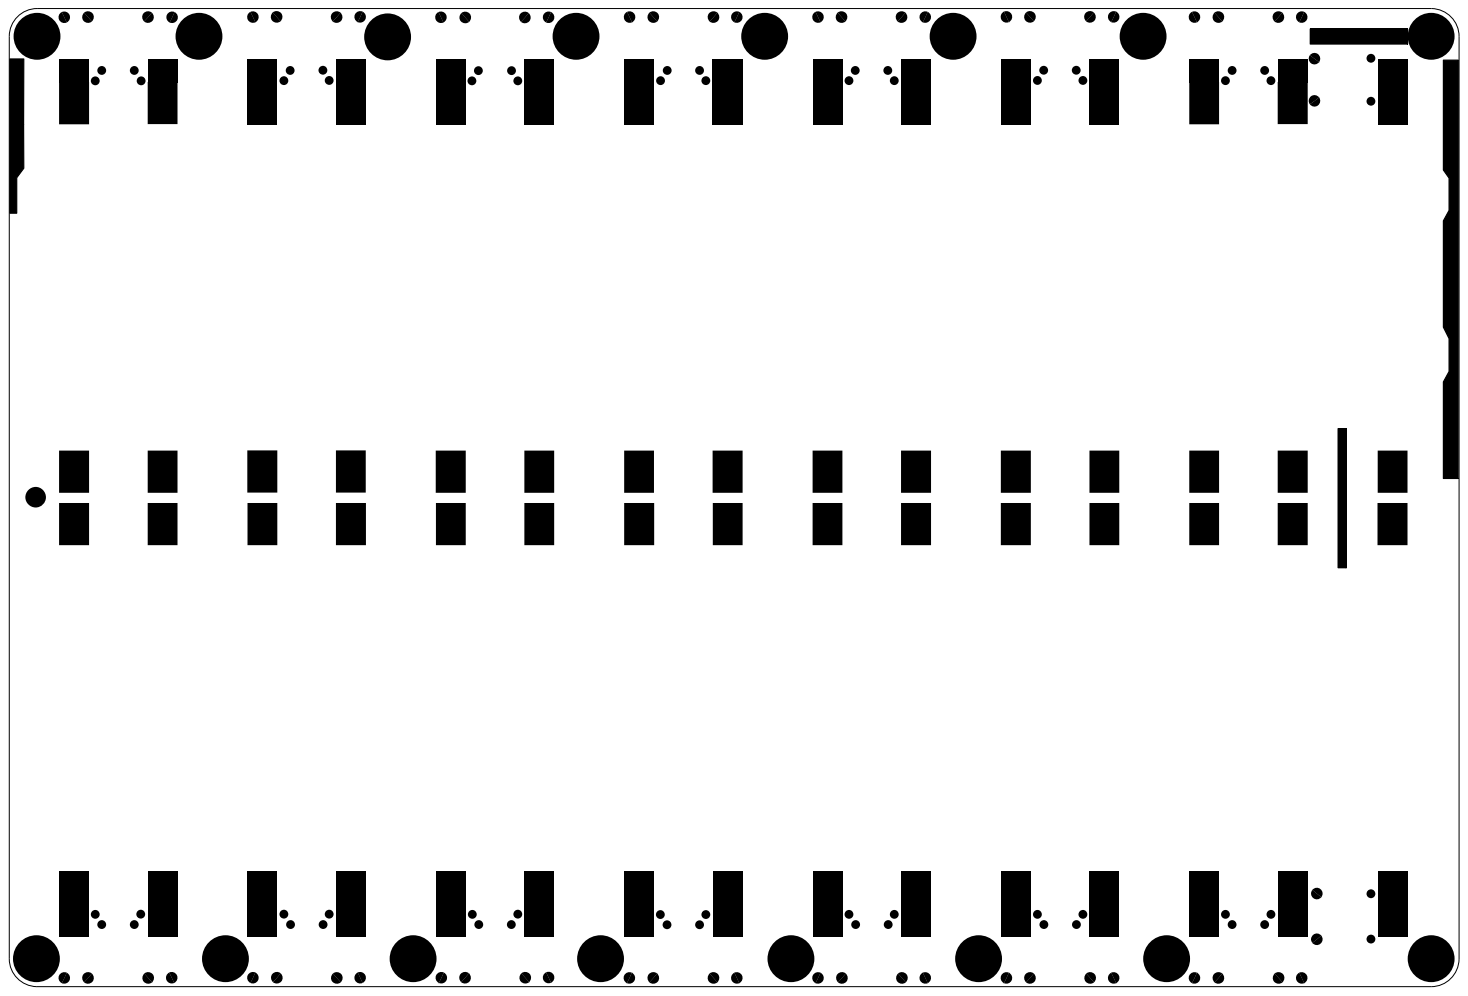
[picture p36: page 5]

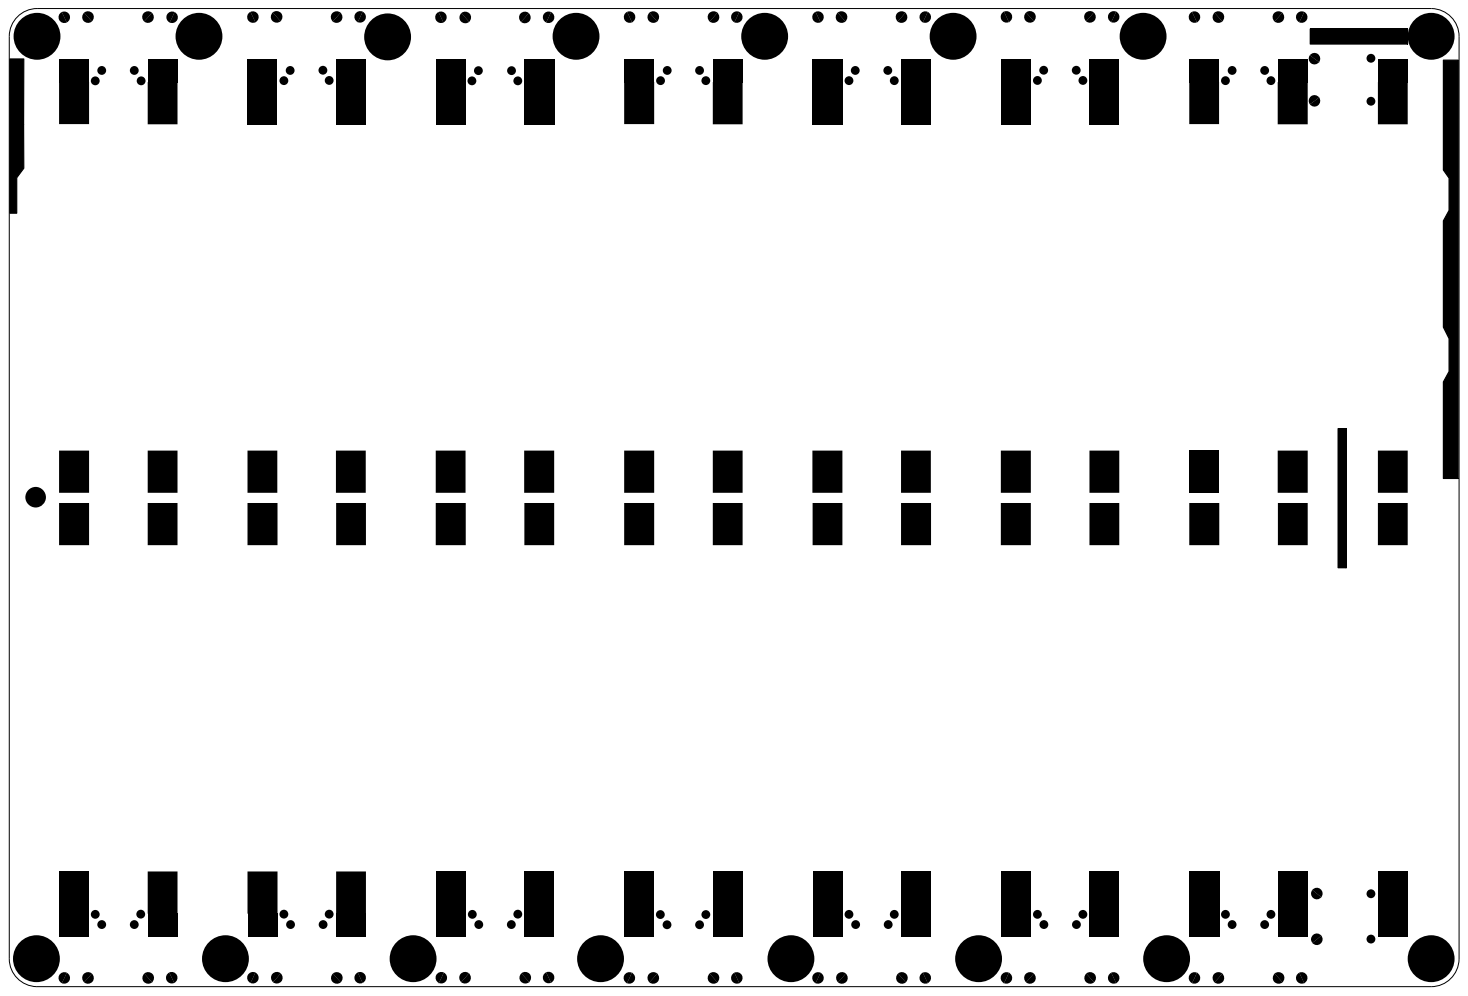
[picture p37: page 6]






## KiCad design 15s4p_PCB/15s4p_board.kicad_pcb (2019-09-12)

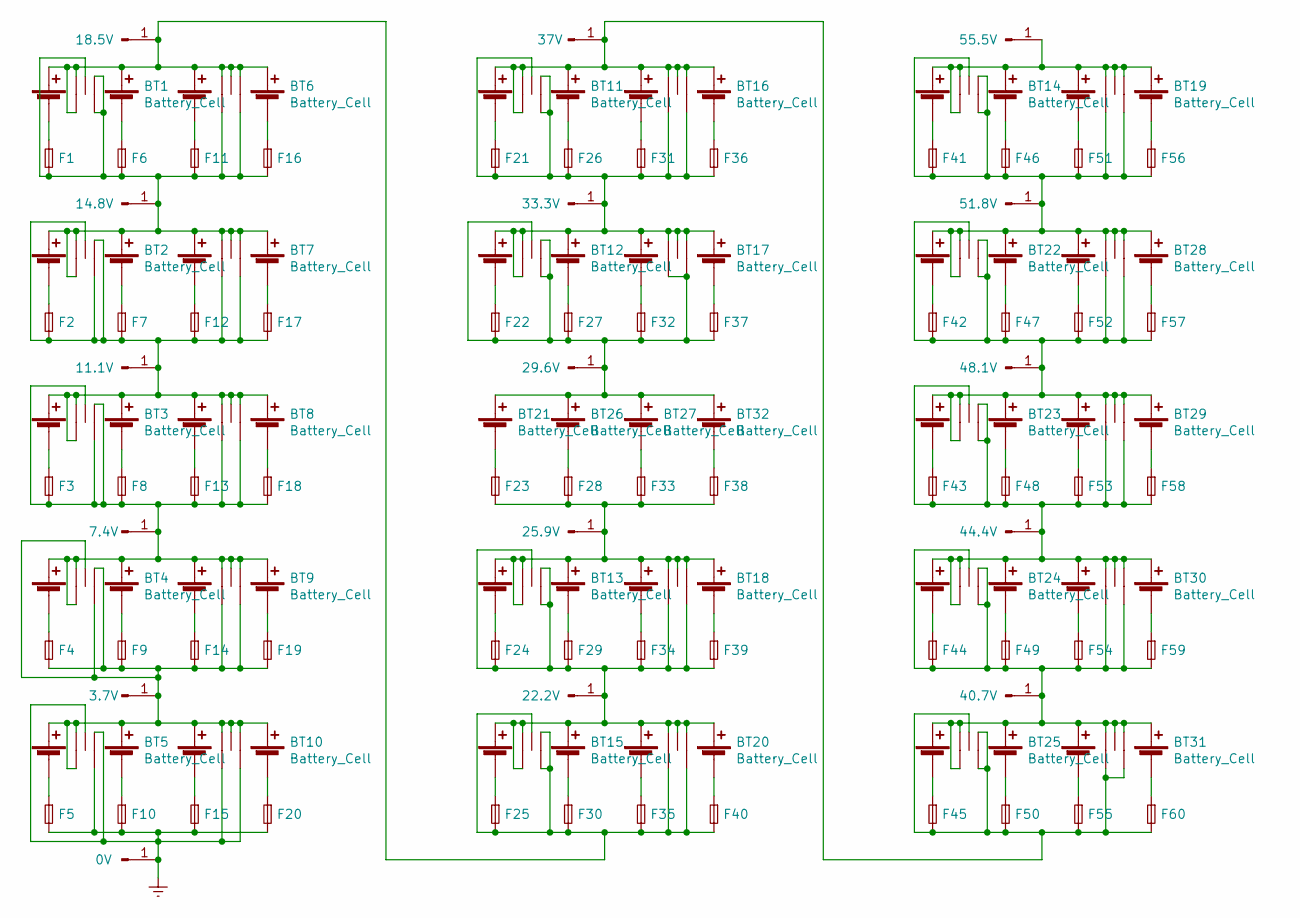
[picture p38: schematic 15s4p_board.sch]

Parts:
BT1, BT2, BT3, BT4, BT5, BT6, BT7, BT8, BT9, BT10, BT11, BT12, BT13, BT14, BT15, BT16, BT17, BT18, BT19, BT20, BT22, BT23, BT24, BT25, BT28, BT29, BT30, BT31: Battery_Cell; 2cell_dual_holder_longer
BT21, BT26, BT27, BT32: Battery_Cell; single_cell_dual_holder
F1, F2, F3, F4, F5, F6, F7, F8, F9, F10, F11, F12, F13, F14, F15, F16, F17, F18, F19, F20, F21, F22, F23, F24, F25, F26, F27, F28, F29, F30, F31, F32, F33, F34, F35, F36, F37, F38, F39, F40, F41, F42, F43, F44, F45, F46, F47, F48, F49, F50, F51, F52, F53, F54, F55, F56, F57, F58, F59, F60: Fuse_Small; fuse
J1: 18.5V; hole
J2: 14.8V; hole
J3: 11.1V; hole
J4: 7.4V; hole
J5: 3.7V; hole
J6: 0V; hole
J7: 37V; hole
J8: 33.3V; hole
J9: 29.6V; hole
J10: 25.9V; hole
J11: 22.2V; hole
J12: 55.5V; hole
J13: 51.8V; hole
J14: 48.1V; hole
J15: 44.4V; hole
J16: 40.7V; hole

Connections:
Earth: BT5.6 (rr), BT5.8, BT5.9, BT10.5 (f), BT10.6 (rr), F5.2, F10.2, F15.2, F20.2, J6.1
unnamed: BT1.1 (+), BT1.3 (+), BT1.5 (f), BT1.7 (tt), BT6.1 (+), BT6.3 (+), BT6.7 (tt), BT6.8, BT6.9, BT15.6 (rr), BT15.8, BT15.9, BT20.5 (f), BT20.6 (rr), F25.2, F30.2, F35.2, F40.2, J1.1
unnamed: BT1.2 (-), F1.1
unnamed: BT1.4 (-), F6.1
unnamed: BT1.6 (rr), BT1.8, BT1.9, BT2.1 (+), BT2.3 (+), BT2.5 (f), BT2.7 (tt), BT6.5 (f), BT6.6 (rr), BT7.1 (+), BT7.3 (+), BT7.7 (tt), BT7.8, BT7.9, F1.2, F6.2, F11.2, F16.2, J2.1
unnamed: BT2.2 (-), F2.1
unnamed: BT2.4 (-), F7.1
unnamed: BT2.6 (rr), BT2.8, BT2.9, BT3.1 (+), BT3.3 (+), BT3.5 (f), BT3.7 (tt), BT7.5 (f), BT7.6 (rr), BT8.1 (+), BT8.3 (+), BT8.7 (tt), BT8.8, BT8.9, F2.2, F7.2, F12.2, F17.2, J3.1
unnamed: BT3.2 (-), F3.1
unnamed: BT3.4 (-), F8.1
unnamed: BT3.6 (rr), BT3.8, BT3.9, BT4.1 (+), BT4.3 (+), BT4.5 (f), BT4.7 (tt), BT8.5 (f), BT8.6 (rr), BT9.1 (+), BT9.3 (+), BT9.7 (tt), BT9.8, BT9.9, F3.2, F8.2, F13.2, F18.2, J4.1
unnamed: BT4.2 (-), F4.1
unnamed: BT4.4 (-), F9.1
unnamed: BT5.2 (-), F5.1
unnamed: BT5.4 (-), F10.1
unnamed: BT6.2 (-), F11.1
unnamed: BT6.4 (-), F16.1
unnamed: BT7.2 (-), F12.1
unnamed: BT7.4 (-), F17.1
unnamed: BT8.2 (-), F13.1
unnamed: BT8.4 (-), F18.1
unnamed: BT9.2 (-), F14.1
unnamed: BT9.4 (-), F19.1
unnamed: BT4.6 (rr), BT4.8, BT4.9, BT5.1 (+), BT5.3 (+), BT5.5 (f), BT5.7 (tt), BT9.5 (f), BT9.6 (rr), BT10.1 (+), BT10.3 (+), BT10.7 (tt), BT10.8, BT10.9, F4.2, F9.2, F14.2, F19.2, J5.1
unnamed: BT10.2 (-), F15.1
unnamed: BT10.4 (-), F20.1
unnamed: BT11.1 (+), BT11.3 (+), BT11.5 (f), BT11.7 (tt), BT16.1 (+), BT16.3 (+), BT16.7 (tt), BT16.8, BT16.9, BT25.6 (rr), BT25.8, BT25.9, BT31.5 (f), BT31.6 (rr), F45.2, F50.2, F55.2, F60.2, J7.1
unnamed: BT11.2 (-), F21.1
unnamed: BT11.4 (-), F26.1
unnamed: BT11.6 (rr), BT11.8, BT11.9, BT12.1 (+), BT12.3 (+), BT12.5 (f), BT12.7 (tt), BT16.5 (f), BT16.6 (rr), BT17.1 (+), BT17.3 (+), BT17.7 (tt), BT17.8, BT17.9, F21.2, F26.2, F31.2, F36.2, J8.1
unnamed: BT12.2 (-), F22.1
unnamed: BT12.4 (-), F27.1
unnamed: BT13.2 (-), F24.1
unnamed: BT13.4 (-), F29.1
unnamed: BT13.6 (rr), BT13.8, BT13.9, BT15.1 (+), BT15.3 (+), BT15.5 (f), BT15.7 (tt), BT18.5 (f), BT18.6 (rr), BT20.1 (+), BT20.3 (+), BT20.7 (tt), BT20.8, BT20.9, F24.2, F29.2, F34.2, F39.2, J11.1
unnamed: BT14.1 (+), BT14.3 (+), BT14.5 (f), BT14.7 (tt), BT19.1 (+), BT19.3 (+), BT19.7 (tt), BT19.8, BT19.9, J12.1
unnamed: BT14.2 (-), F41.1
unnamed: BT14.4 (-), F46.1
unnamed: BT14.6 (rr), BT14.8, BT14.9, BT19.5 (f), BT19.6 (rr), BT22.1 (+), BT22.3 (+), BT22.5 (f), BT22.7 (tt), BT28.1 (+), BT28.3 (+), BT28.7 (tt), BT28.8, BT28.9, F41.2, F46.2, F51.2, F56.2, J13.1
unnamed: BT15.2 (-), F25.1
unnamed: BT15.4 (-), F30.1
unnamed: BT16.2 (-), F31.1
unnamed: BT16.4 (-), F36.1
unnamed: BT17.2 (-), F32.1
unnamed: BT17.4 (-), F37.1
unnamed: BT18.2 (-), F34.1
unnamed: BT18.4 (-), F39.1
unnamed: BT19.2 (-), F51.1
unnamed: BT19.4 (-), F56.1
unnamed: BT20.2 (-), F35.1
unnamed: BT20.4 (-), F40.1
unnamed: BT21.2 (-), F23.1
unnamed: BT22.2 (-), F42.1
unnamed: BT22.4 (-), F47.1
unnamed: BT22.6 (rr), BT22.8, BT22.9, BT23.1 (+), BT23.3 (+), BT23.5 (f), BT23.7 (tt), BT28.5 (f), BT28.6 (rr), BT29.1 (+), BT29.3 (+), BT29.7 (tt), BT29.8, BT29.9, F42.2, F47.2, F52.2, F57.2, J14.1
unnamed: BT23.2 (-), F43.1
unnamed: BT23.4 (-), F48.1
unnamed: BT23.6 (rr), BT23.8, BT23.9, BT24.1 (+), BT24.3 (+), BT24.5 (f), BT24.7 (tt), BT29.5 (f), BT29.6 (rr), BT30.1 (+), BT30.3 (+), BT30.7 (tt), BT30.8, BT30.9, F43.2, F48.2, F53.2, F58.2, J15.1
unnamed: BT24.2 (-), F44.1
unnamed: BT24.4 (-), F49.1
unnamed: BT24.6 (rr), BT24.8, BT24.9, BT25.1 (+), BT25.3 (+), BT25.5 (f), BT25.7 (tt), BT30.5 (f), BT30.6 (rr), BT31.1 (+), BT31.3 (+), BT31.7 (tt), BT31.8, BT31.9, F44.2, F49.2, F54.2, F59.2, J16.1
unnamed: BT25.2 (-), F45.1
unnamed: BT25.4 (-), F50.1
unnamed: BT26.2 (-), F28.1
unnamed: BT27.2 (-), F33.1
unnamed: BT28.2 (-), F52.1
unnamed: BT28.4 (-), F57.1
unnamed: BT29.2 (-), F53.1
unnamed: BT29.4 (-), F58.1
unnamed: BT30.2 (-), F54.1
unnamed: BT30.4 (-), F59.1
unnamed: BT31.2 (-), F55.1
unnamed: BT31.4 (-), F60.1
unnamed: BT32.2 (-), F38.1

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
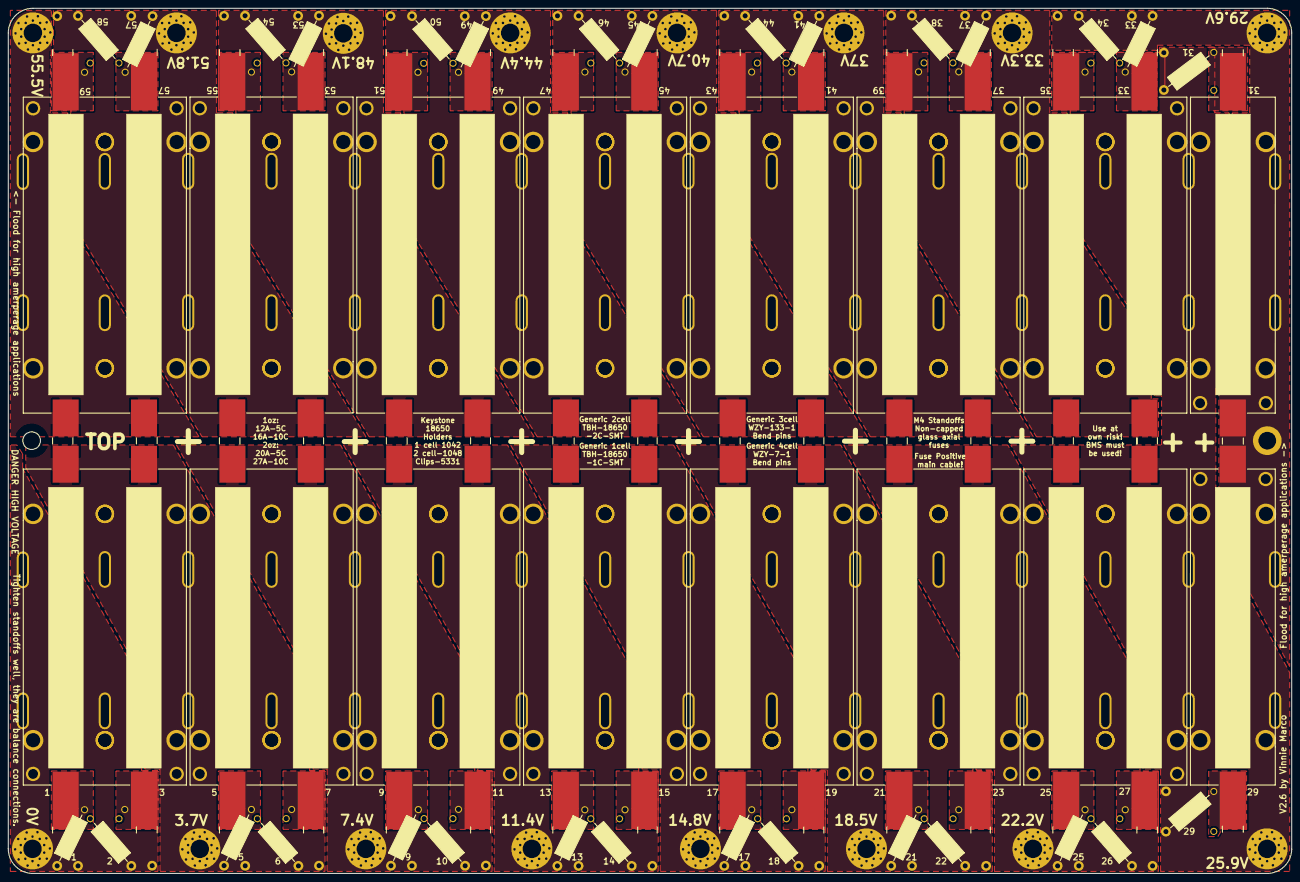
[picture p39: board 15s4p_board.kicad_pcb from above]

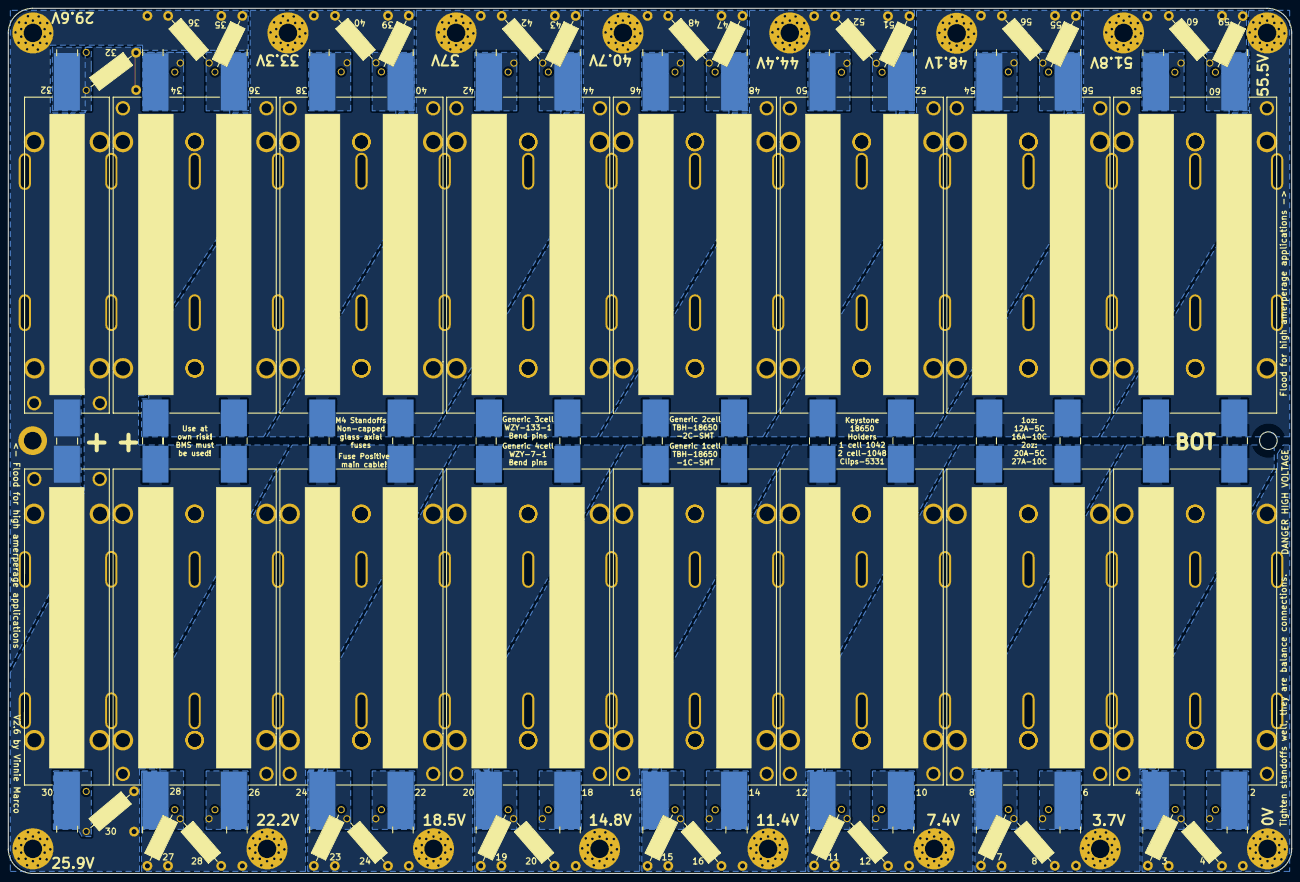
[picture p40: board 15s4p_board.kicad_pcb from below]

Board: 2 copper layers, 313.0 x 211.0 mm, 108 parts (46 on the bottom side), 76 nets.

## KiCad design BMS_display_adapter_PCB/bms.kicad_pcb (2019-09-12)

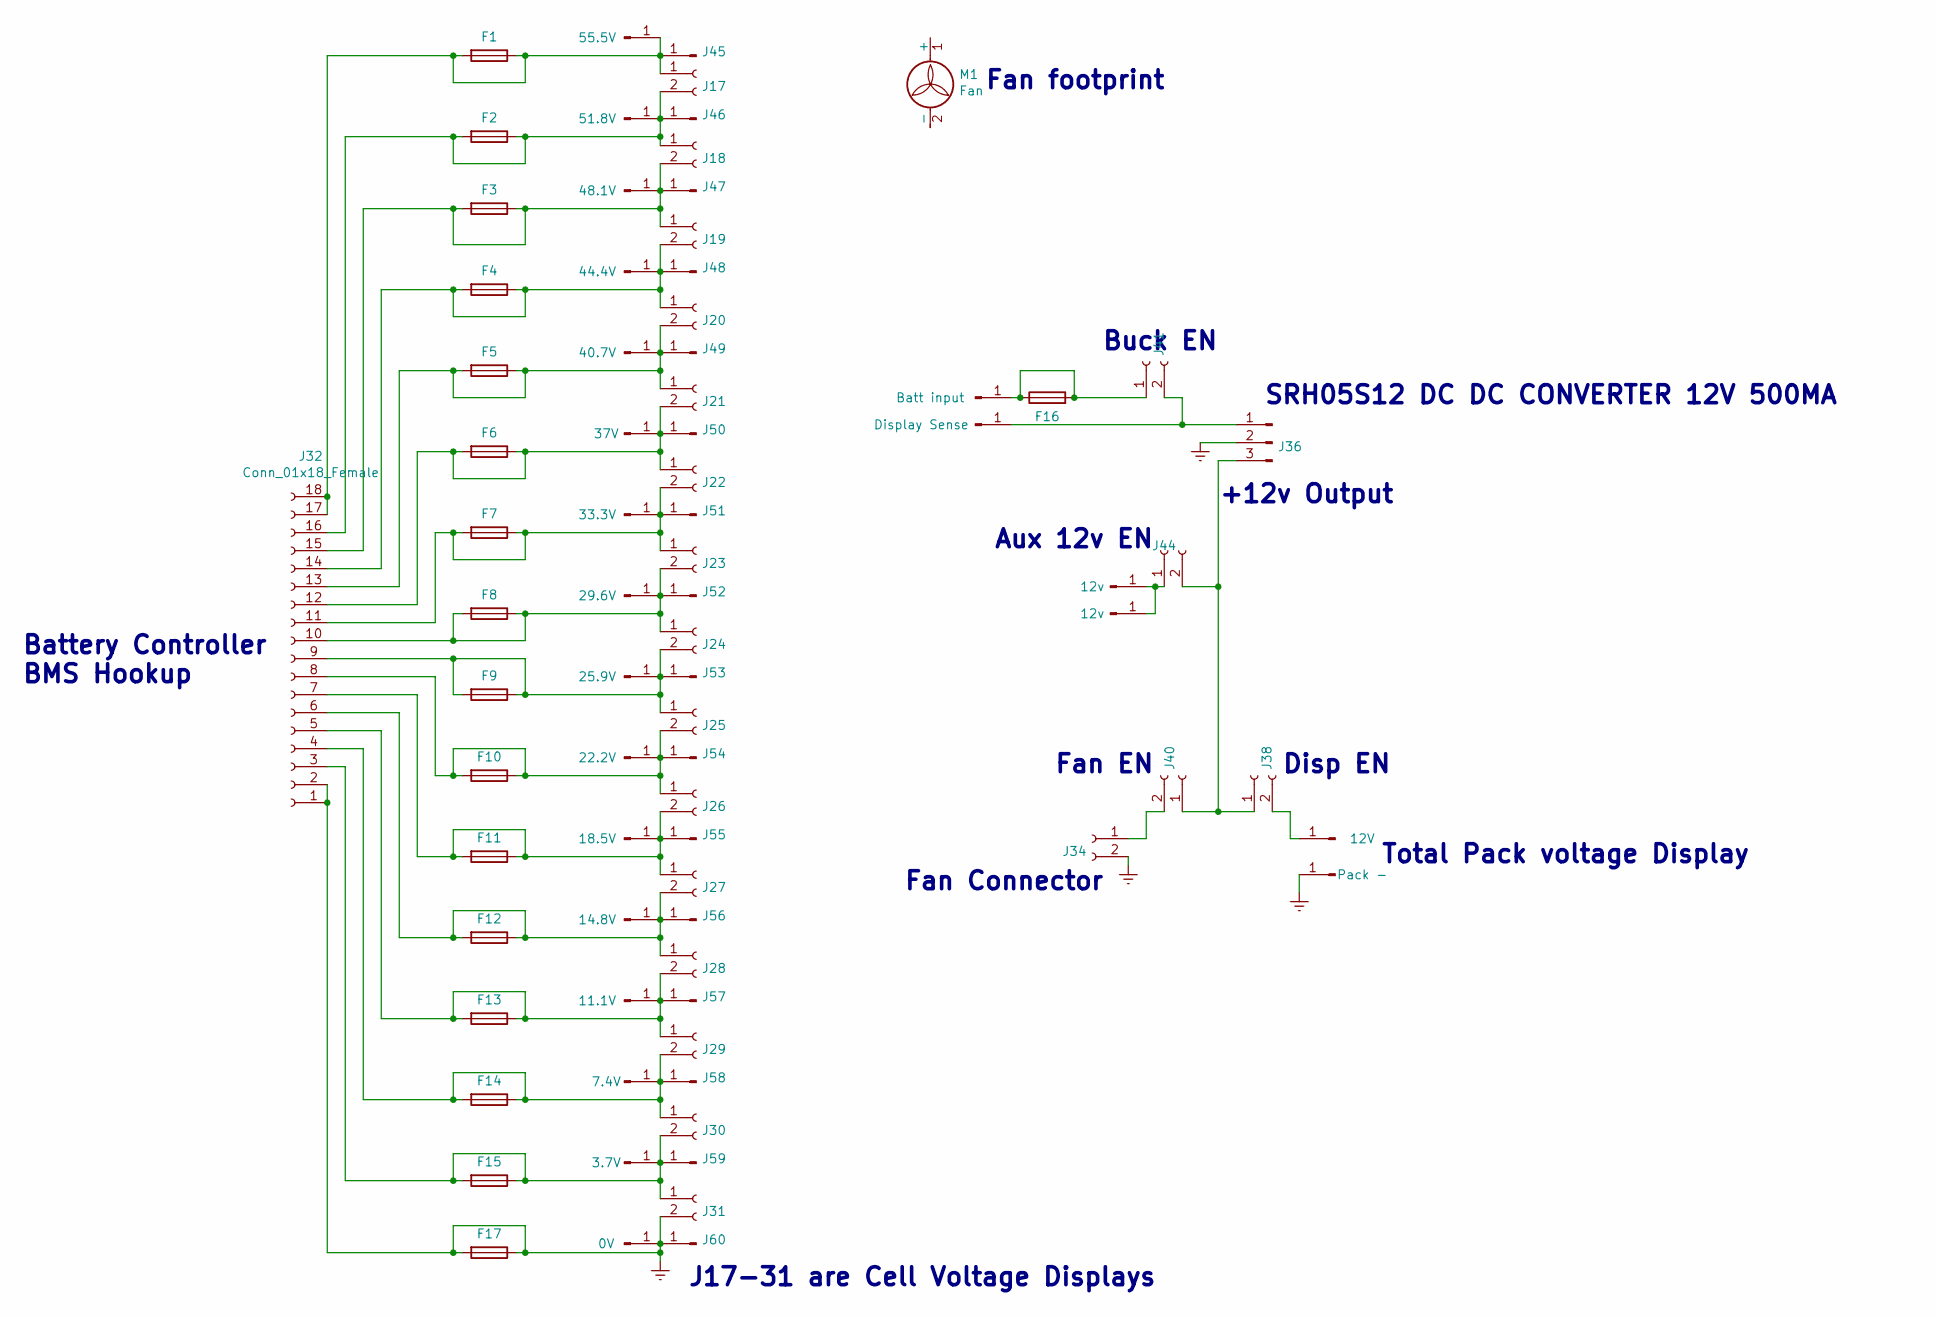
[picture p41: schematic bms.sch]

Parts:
F1, F2, F3, F4, F5, F6, F7, F8, F9, F10, F11, F12, F13, F14, F15, F16, F17: Fuse
J1: 55.5V; hole
J2: 51.8V; hole
J3: 48.1V; hole
J4: 44.4V; hole
J5: 40.7V; hole
J6: 37V; hole
J7: 33.3V; hole
J8: 29.6V; hole
J9: 25.9V; hole
J10: 22.2V; hole
J11: 18.5V; hole
J12: 14.8V; hole
J13: 11.1V; hole
J14: 7.4V; hole
J15: 3.7V; hole
J16: 0V; hole
J17, J18, J19, J20, J21, J22, J23, J24, J25, J26, J27, J28, J29, J30, J31: Conn_01x02_Female; VoltMeter
J32: Conn_01x18_Female; BMS_module
J33: Display Sense; hole
J34: Conn_01x02_Female; fan_holes
J35: 12V; hole
J36: Conn_01x03_Male; Buck converter
J37: Pack -; hole
J38, J40, J41, J44: Conn_01x02_Female; jumper
J39: Batt input; hole
J42, J43: 12v; hole
J45, J46, J47, J48, J49, J50, J51, J52, J53, J54, J55, J56, J57, J58, J59, J60: Conn_01x01_Male; B4A-PCB
M1: Fan; 40mm_fan

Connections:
Earth: F17.1, F17.2, J16.1, J31.2, J32.1, J32.2, J34.2, J36.2, J37.1, J60.1
unnamed: F1.1, F1.2, J1.1, J17.1, J32.17, J32.18, J45.1
unnamed: F2.1, F2.2, J2.1, J17.2, J18.1, J32.16, J46.1
unnamed: F3.1, F3.2, J3.1, J18.2, J19.1, J32.15, J47.1
unnamed: F4.1, F4.2, J4.1, J19.2, J20.1, J32.14, J48.1
unnamed: F5.1, F5.2, J5.1, J20.2, J21.1, J32.13, J49.1
unnamed: F6.1, F6.2, J6.1, J21.2, J22.1, J32.12, J50.1
unnamed: F7.1, F7.2, J7.1, J22.2, J23.1, J32.11, J51.1
unnamed: F8.1, F8.2, J8.1, J23.2, J24.1, J32.10, J52.1
unnamed: F9.1, F9.2, J9.1, J24.2, J25.1, J32.9, J53.1
unnamed: F10.1, F10.2, J10.1, J25.2, J26.1, J32.8, J54.1
unnamed: F11.1, F11.2, J11.1, J26.2, J27.1, J32.7, J55.1
unnamed: F12.1, F12.2, J12.1, J27.2, J28.1, J32.6, J56.1
unnamed: F13.1, F13.2, J13.1, J28.2, J29.1, J32.5, J57.1
unnamed: F14.1, F14.2, J14.1, J29.2, J30.1, J32.4, J58.1
unnamed: F15.1, F15.2, J15.1, J30.2, J31.1, J32.3, J59.1
unnamed: F16.1, F16.2, J39.1, J41.1
unnamed: J33.1, J36.1, J41.2
unnamed: J34.1, J40.2
unnamed: J35.1, J38.2
unnamed: J36.3, J38.1, J40.1, J44.2
unnamed: J42.1, J43.1, J44.1

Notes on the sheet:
Total Pack voltage Display
J17-31 are Cell Voltage Displays
Battery Controller BMS Hookup
SRH05S12 DC DC CONVERTER 12V 500MA
Disp EN
Buck EN
Aux 12v EN
+12v Output
Fan footprint
Fan Connector
Fan EN

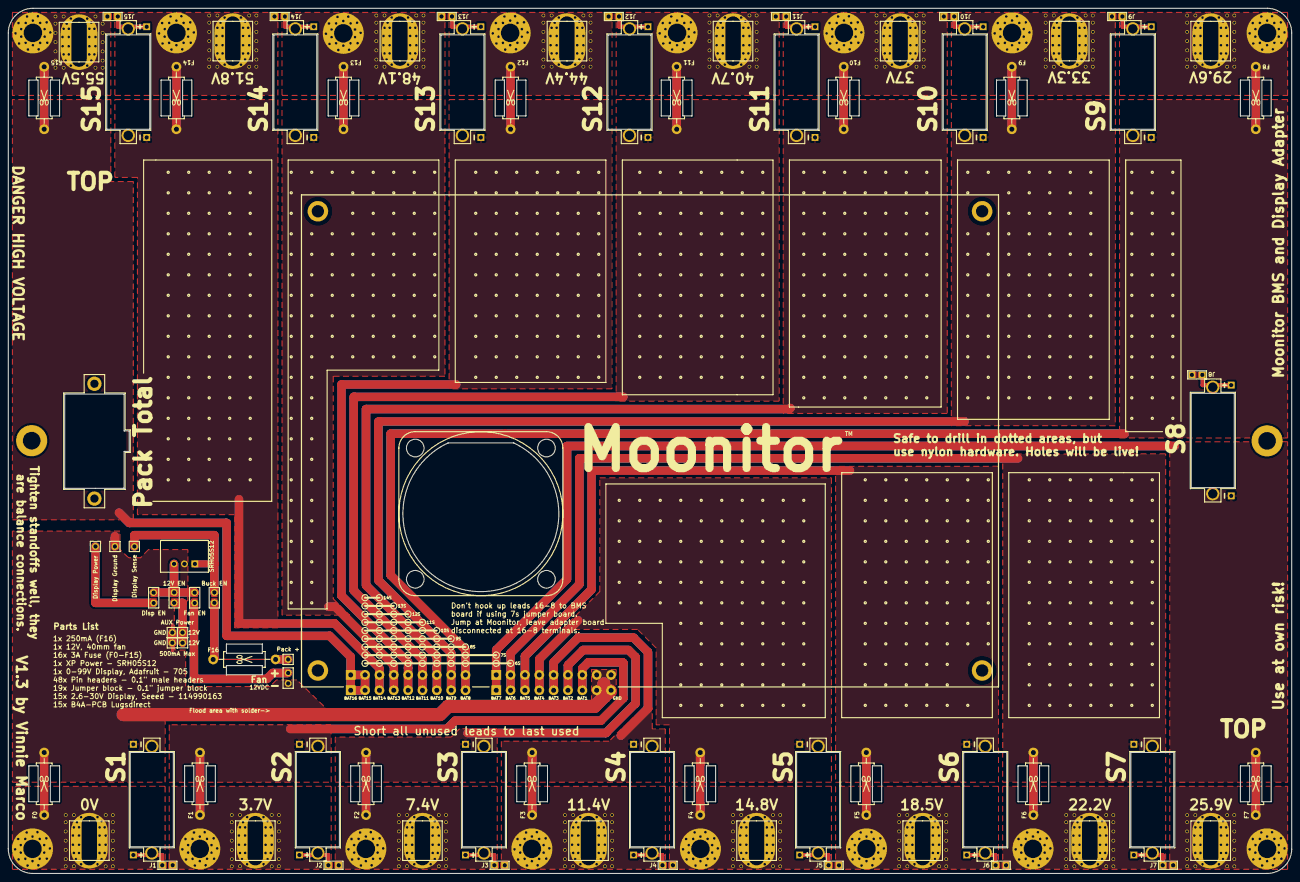
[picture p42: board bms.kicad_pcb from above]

Board: 2 copper layers, 313.0 x 211.0 mm, 78 parts (0 on the bottom side), 22 nets.

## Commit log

2019-07-31 V1.0 Release
    [7sAdapter.sch, 7sAdapter.step]
2019-07-31 V2.4 Release
    First public release of 15s4p PCB
    [1042--3DModel-STEP-56544.STEP, 15s4p_board.kicad_pcb, 15s4p_board.sch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]
2019-07-31 V1.1 Release
    First public release of the BMS/Display Adapter PCB
    [40x40x10 DC Fan.STEP, LED DC 0-100V Digital Voltmeter Panel Meter.STEP, bms.kicad_pcb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]
2019-08-06 adding screw terminals
    [_STP FILES_B2A-PCB-Assembly.stp]
2019-08-08 moving displays to make room for lugs
    [_STP FILES_B4A-PCB-HEX.stp, bms.kicad_pcb, bms.sch]
2019-08-08 redrawing planes
    [bms.kicad_pcb]
2019-08-09 footprint updates
    [bms.kicad_pcb, bms.sch]
2019-08-13 V1.2 Release
    [bms.kicad_pcb, bms.sch]
2019-08-13 V1.1 Release
    Increased standoff hole size and via layout
2019-08-13 V2.5 Release
    updated standoff pads
    [15s4p_board.kicad_pcb]
2019-08-13 V1.2 Release
    Updated standoff mounting holes
    [bms-B_Cu.gbr, bms-B_Mask.gbr, bms-B_SilkS.gbr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]
2019-08-13 V1.2 Release
    mvoed gerbers to zip file
    [bms-B_Cu.gbr, bms-B_Mask.gbr, bms-B_SilkS.gbr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]
2019-08-13 updated 3d models
    [bms.kicad_pcb]
2019-08-14 fixed save-file issue
    [15s4p_board.kicad_pcb]
2019-09-12 V1.3 updates
    [bms.kicad_pcb]
2019-09-12 V1.3 Release
    [bms.kicad_pcb]
2019-09-12 Updated Flood Mask
    [15s4p_board.kicad_pcb]
